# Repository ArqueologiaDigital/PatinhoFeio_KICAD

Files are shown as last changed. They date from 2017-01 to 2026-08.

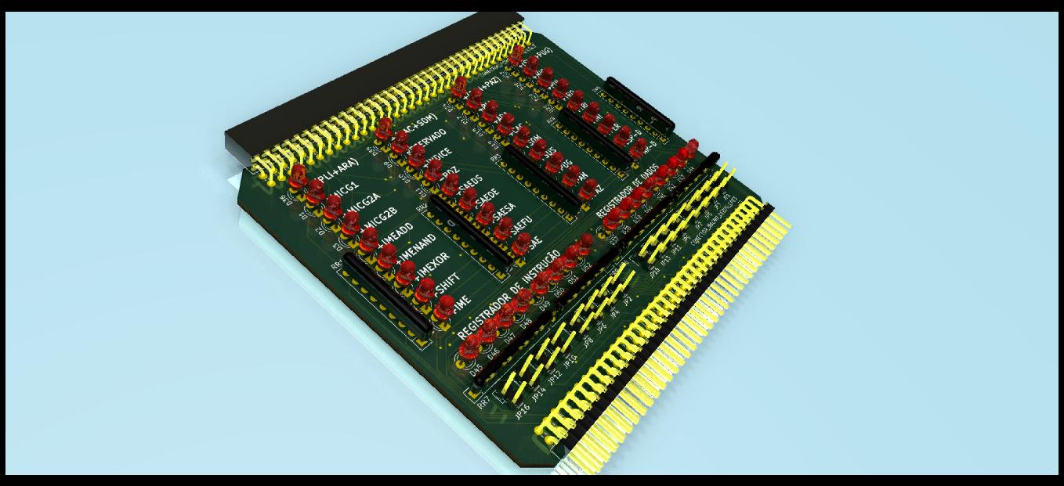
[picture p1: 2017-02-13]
CDE-3-debug/CDE-3-debug.jpg

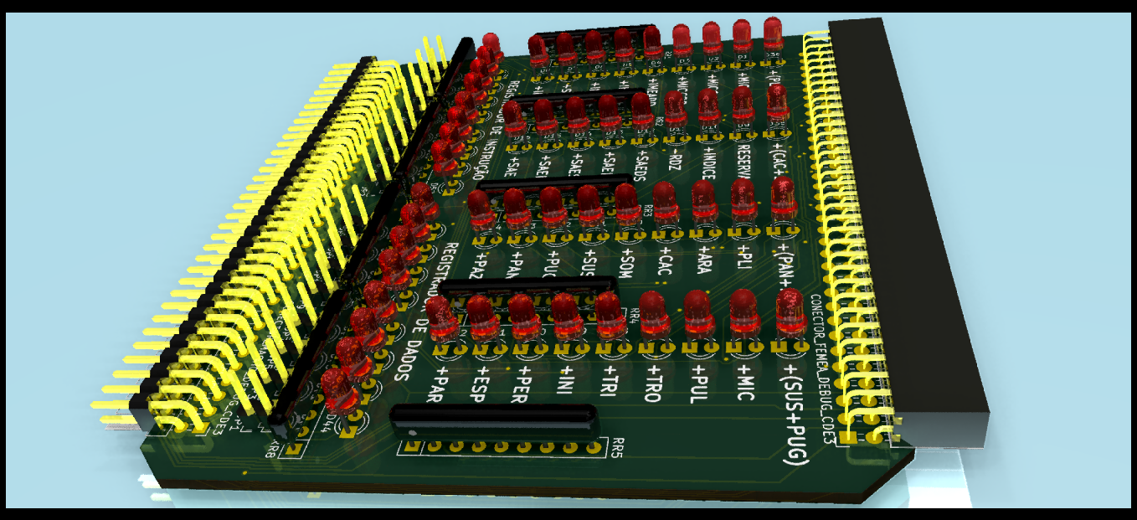
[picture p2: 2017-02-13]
CDE-3-debug/CDE-3-debug_1.png

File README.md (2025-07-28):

Para o desenvolvimento desse projeto estou atualmente (Julho de 2025) utilizando o Kicad versão 9.0.2+dfsg-1 instalado a partir do repositório de pacotes do Debian 13.
----

Existe um arquivo patinhofeio.pro na raiz desse repo que referencia os demais sub-projetos de cada placa.

Em JAN/2018 eu encomendei a fabicação das PCBs CDE-3 e CDE-3-debug. Há um relato detalhado em https://forum.fiozera.com.br/t/resgate-historico-do-computador-patinho-feio-usp-1971/58/18

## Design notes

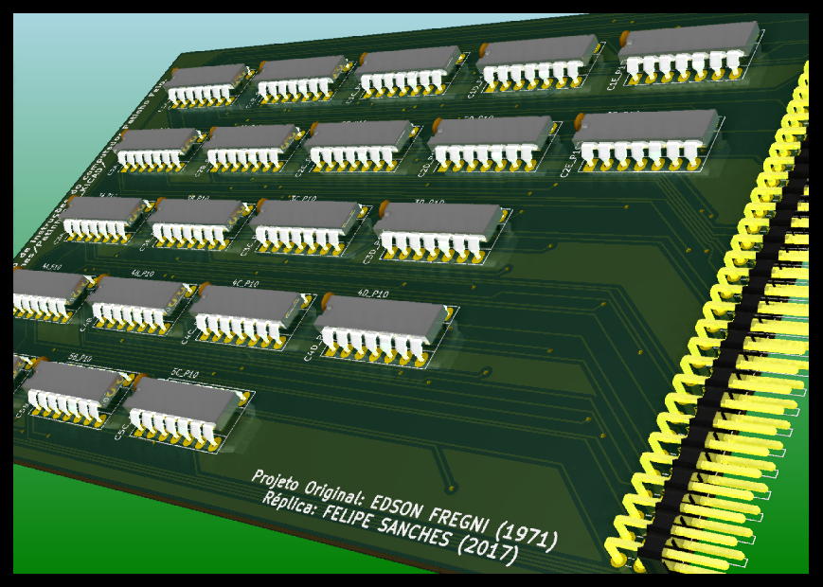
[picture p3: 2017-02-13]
CDE-3/CDE-3.png

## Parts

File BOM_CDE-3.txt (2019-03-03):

 1 7400
 7 7402
 6 7404
 5 7410
 1 7413
 1 7430
21 capacitores cerâmicos 0.1uF
21 soquete DIP14
 2 barra de pinos 90 graus 35x2 macho
 2 conector 90 graus 35x2 fêmea
 2 barra de pinos 16x2 macho
16 jumpers
60 leds vermelhos 3mm
 9 Redes resistivas 9 pinos 330ohms
 9 Redes resistivas 9 pinos 470ohms
 9 Redes resistivas 9 pinos 1k
 9 Redes resistivas 9 pinos 10k
 20 resitores 330ohms
 20 resitores 470ohms
 20 resitores 1k
 20 resitores 10k

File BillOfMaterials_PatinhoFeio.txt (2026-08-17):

== FR1-1 ==
Pastilhas:
* 1x 74LS00
* 2x SN74LS51B1
* 2x SN7454N
* 10x 74LS74

Discretos:
* 15x caps
* 1x conn_35x2

== FR2-2 ==
Pastilhas:
* 1x 74LS00
* 2x SN74LS51B1
* 2x SN7454N
* 10x 74LS74

Discretos:
* 15x caps
* 1x conn_35x2

== CRC-1 ==
Pastilhas:
* 2x 74LS00
* 8x 74LS04
* 1x 74LS10
* 4x 74LS74

Discretos:
* 15x caps
* 1x conn_35x2
* 1x XTAL (freq. ?)
* 3x BF185 (transistor TO92)
* 6 resistores sortidos (ver equemático)
* 5 caps sortidos (ver equemático)

== CDE-3 ==
Pastilhas:
* 1x 74LS00
* 7x 74LS02
* 6x 74LS04
* 5x 74LS10
* 1x 74LS20
* 1x 74LS30

Discretos:
* 21x caps
* 1x conn_35x2

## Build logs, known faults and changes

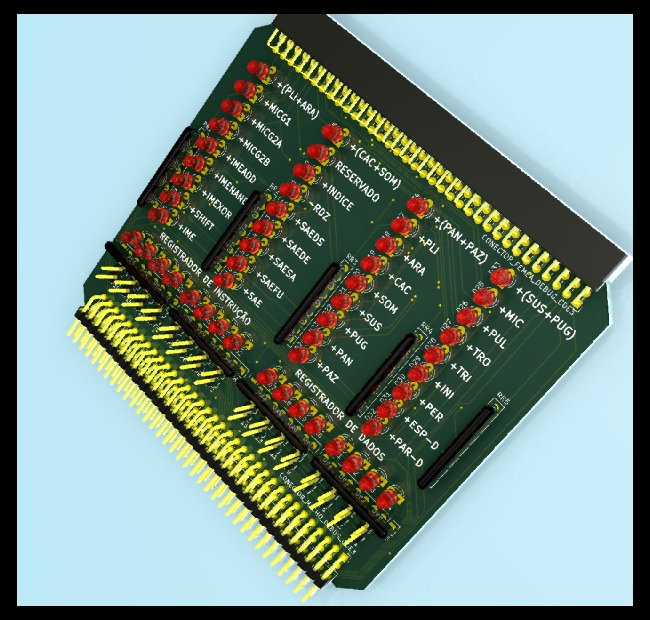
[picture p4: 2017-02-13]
CDE-3-debug/CDE-3-debug_2.png

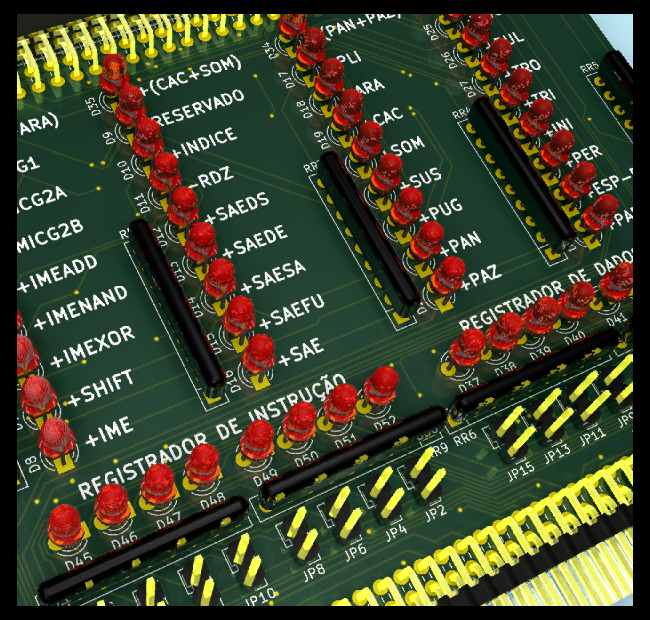
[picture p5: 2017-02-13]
CDE-3-debug/CDE-3-debug_3.png

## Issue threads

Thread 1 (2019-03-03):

CDE-3 (rev b)

felipesanches, 2019-03-03:
A primeira placa CDE-3 produzida tinha alguns erros que foram corrigidos manualmente. Seria bom atualizar o desenho da PCB para que seja possível fabricar uma segunda revisão sem esses erros.

- [ ] Atualizar roteamento da PCB
- [ ] Garantir que passa nos testes de DRC
- [ ] Gerar os gerbers
- [ ] Aplicar tag CDE3_rev_B no repositório
- [ ] Encomendar fabricação da PCB

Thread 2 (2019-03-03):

Prancha XI: Identificar componente 4E

felipesanches, 2019-03-03:
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

É um chip de lógica booleana composto que interliga 4 portas AND a uma porta NOR.

felipesanches, 2019-03-03:
Trata-se de um chip conhecido como "AND-OR-INVERT". É parecido com esse: http://www.applelogic.org/files/74LS54.pdf Mas tem uma outra distribuição de quantidades de inputs.

Estamos procurando algo como `2-4-4-2-INPUT AND-OR-INVERT GATE`.

felipesanches, 2019-03-03:
Essa mesma prancha tem um outro CI que parece ser do mesmo tipo:

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

felipesanches, 2019-03-03:
É muito difícil de ler o que está escrito. Mas parece ser:

Primeira porta AND:
* 2A1
* 2A13

Segunda porta AND:
* 1A13
* 1A2
* 1A1
* 1A3

Terceira porta AND:
* 1A6 (ou 1A8?)
* 1A4
* 1A5
* 1A?

Quarta porta AND:
* 2A8
* 2A10

E a saída da porta NOR parece ser no pino 8. Mas pode também ser pino 6 talvez...

Como constam pinos do chip 1A e 2A, uma hipótese é de que esse símbolo esteja representando duas pastilhas simultaneamente. De fato não consegui achar nenhuma pastilha composta AND-OR-INVERT com esse layout de 2-4-4-2 inputs. Vou tentar encontrar alguma combinação de outras pastilhas AND-OR-INVERT que quando combinadas sejam compatíveis com a pinagem desse diagrama.

lucasalberto01, 2023-08-31:
Consegui encontrar a pastilha _SN74S64_ que é muito próxima, talvez tenham mudado a ordem dos blocos, a pinagem em boa parte é parecida.

Segue o link do PDF do datasheet https://www.ti.com/lit/ds/symlink/sn54s64.pdf

lucasalberto01, 2023-08-31:
Acho que descobri uma coisa... Contando os pinos, vi que na verdade estão usando **13 pinos**, e os 74 tem 14 pinos, 12 são lógicos, 1 para positivo (5v), e 1 para negativo...

 E ali tem dois pinos que estão indo para o terra.... Quem desenhou o esquema provavelmente contou a ligação para o terra como um pino de entra da porta, quando na verdade é só a ligação do negativo do CI com o negativo da alimentação do PC!

lucasalberto01, 2023-08-31:
Uma coisa estranha que percebi é que ali tem 13 pinos usados, e a família 7400 usa 14 pinos

lucasalberto01, 2023-09-11:
Outro circuito integrado, pode ser o 74LS54 **antigo**, o antigo é diferente do novo, era usado no computador HP 9825

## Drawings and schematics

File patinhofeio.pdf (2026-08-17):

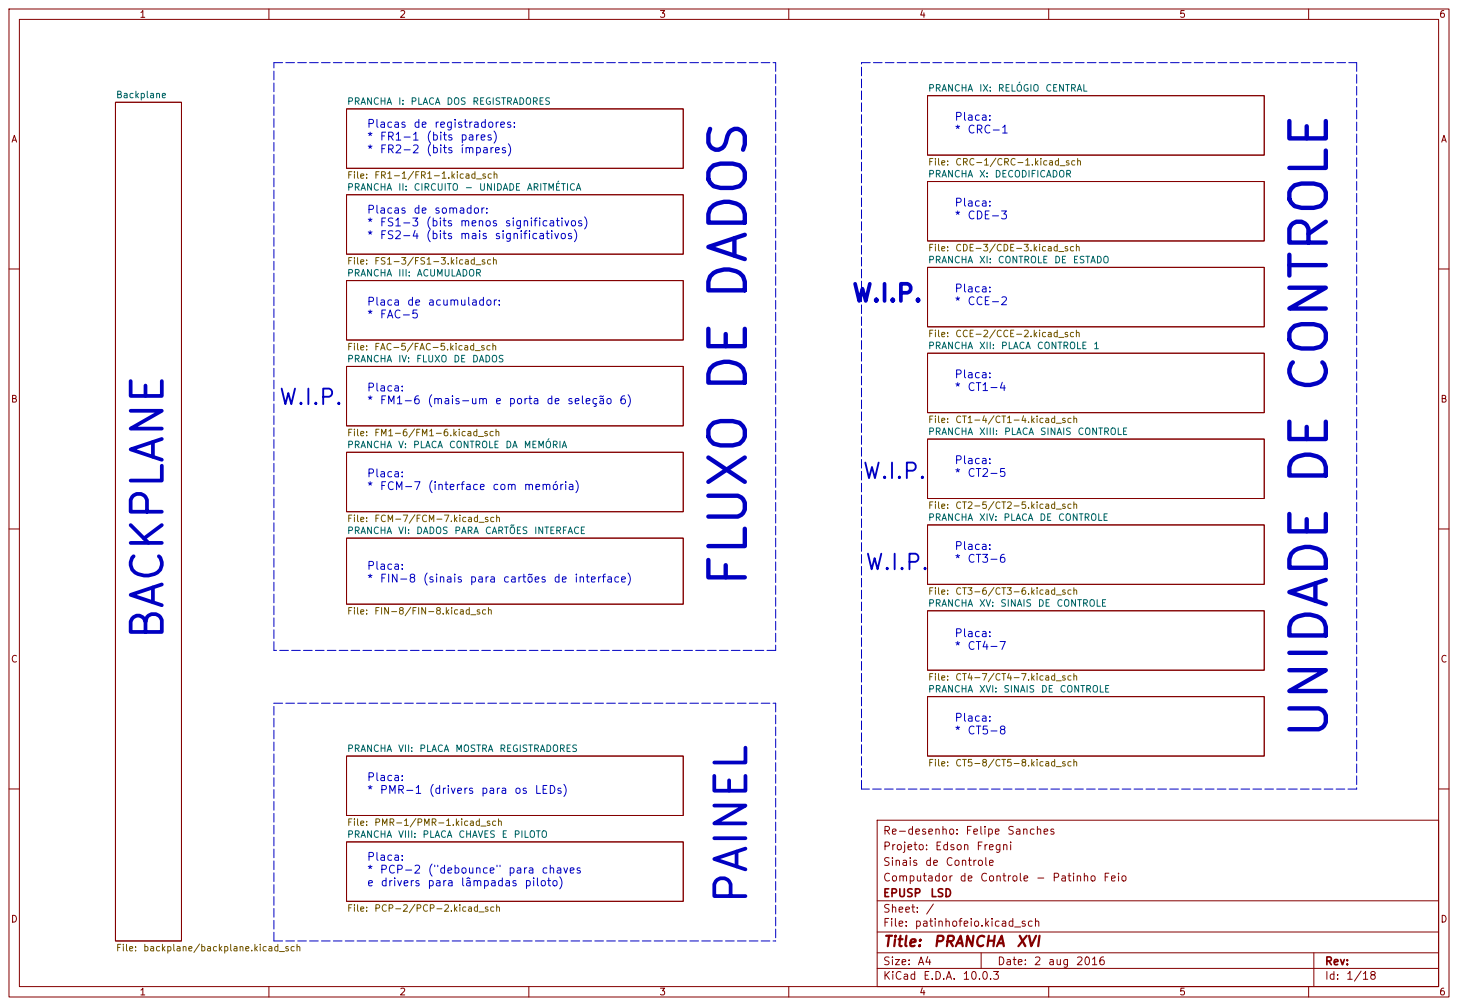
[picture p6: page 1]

File: FCM-7/FCM-7.kicad_sch PRANCHA I: PLACA DOS REGISTRADORES
Placas de registradores:
* FR1-1 (bits pares)
File: FS1-3/FS1-3.kicad_sch PRANCHA VII: PLACA MOSTRA REGISTRADORES
File: CT2-5/CT2-5.kicad_sch PRANCHA III: ACUMULADOR
* CCE-2 PAINEL

File: CCE-2/CCE-2.kicad_sch PRANCHA IX: RELÓGIO CENTRAL File: CRC-1/CRC-1.kicad_sch PRANCHA X: DECODIFICADOR

File: FR1-1/FR1-1.kicad_sch PRANCHA II: CIRCUITO - UNIDADE ARITMÉTICA

File: CDE-3/CDE-3.kicad_sch PRANCHA XII: PLACA CONTROLE 1

File: FAC-5/FAC-5.kicad_sch PRANCHA IV: FLUXO DE DADOS

Placa:
* FM1-6 (mais-um e porta de seleção 6)

File: CT1-4/CT1-4.kicad_sch PRANCHA XVI: SINAIS DE CONTROLE
File: CT4-7/CT4-7.kicad_sch PRANCHA XIII: PLACA SINAIS CONTROLE

File: FM1-6/FM1-6.kicad_sch PRANCHA V: PLACA CONTROLE DA MEMÓRIA

* FCM-7 (interface com memória)

File: CT5-8/CT5-8.kicad_sch PRANCHA XIV: PLACA DE CONTROLE

Re-desenho: Felipe Sanches PRANCHA VI: DADOS PARA CARTÕES INTERFACE

* FIN-8 (sinais para cartões de interface)

File: CT3-6/CT3-6.kicad_sch PRANCHA XV: SINAIS DE CONTROLE

* PMR-1 (drivers para os LEDs)

File: PMR-1/PMR-1.kicad_sch PRANCHA VIII: PLACA CHAVES E PILOTO

Projeto: Edson Fregni
Sinais de Controle
Computador de Controle - Patinho Feio
EPUSP LSD
Sheet: /
File: patinhofeio.kicad_sch
Title: PRANCHA XVI

* PCP-2 ("debounce" para chaves e drivers para lâmpadas piloto)

Size: A4 | Rev:
KiCad E.D.A. 10.0.3 | Id: 1/18

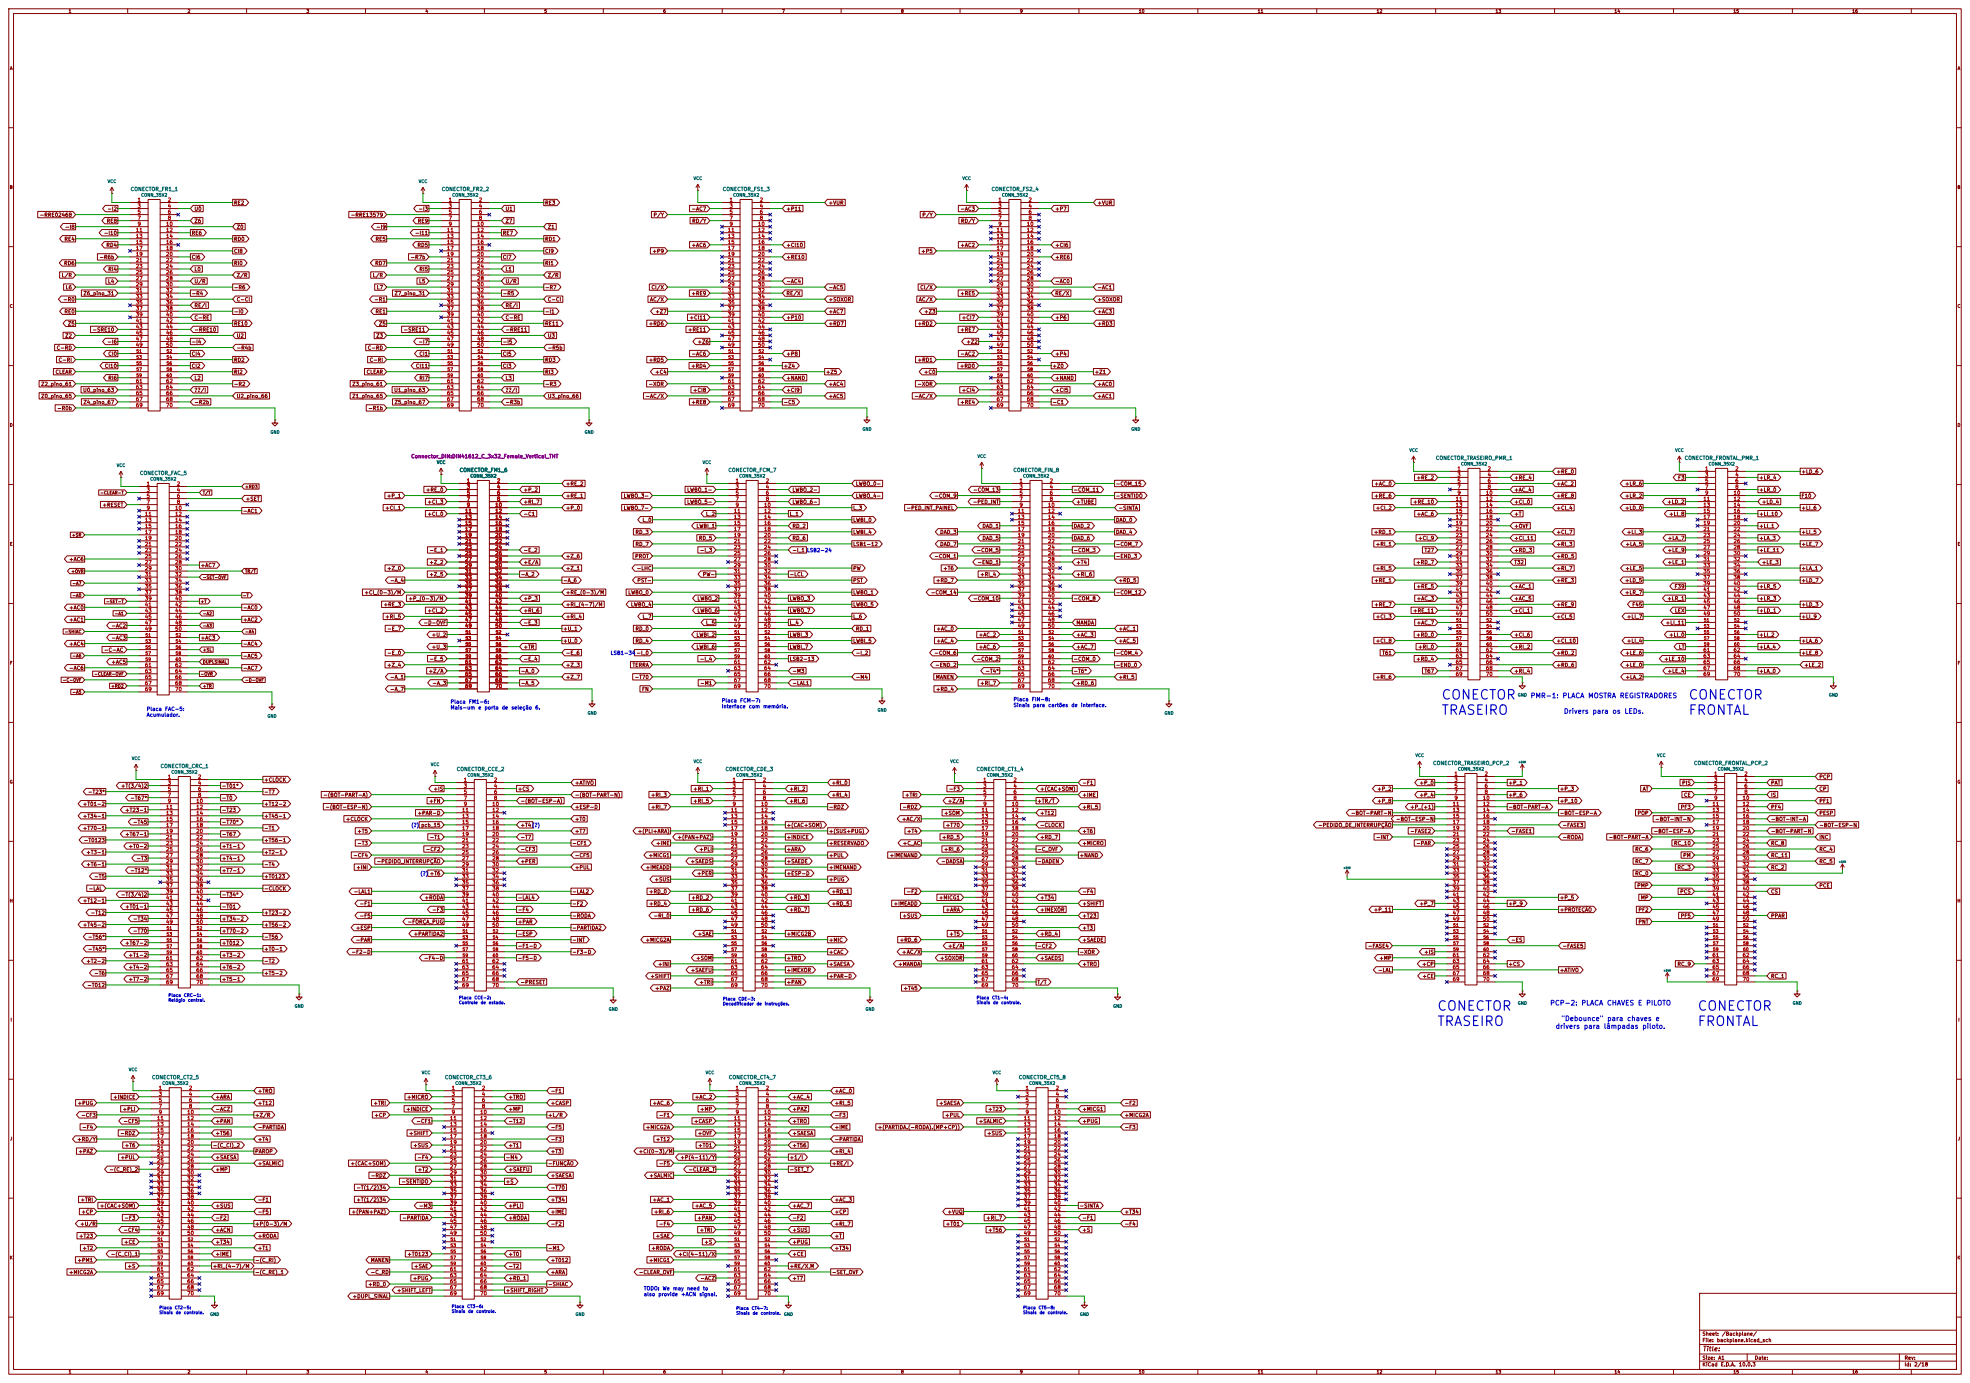
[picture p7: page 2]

PMR-1: PLACA MOSTRA REGISTRADORES
GND

Placa FM1-6:
Mais-um e porta de seleção 6.

Placa FIN-8:
Sinais para cartões de interface.

Drivers para os LEDs.

PCP-2: PLACA CHAVES E PILOTO

"Debounce" para chaves e
drivers para lâmpadas piloto.

+(PARTIDA.(-RODA).(MP+CP))

TODO: We may need to
also provide +ACN signal.

Placa CT3-6: Sinais de controle.

Placa CT5-8: Sinais de controle. Placa CT2-5: Sinais de controle.

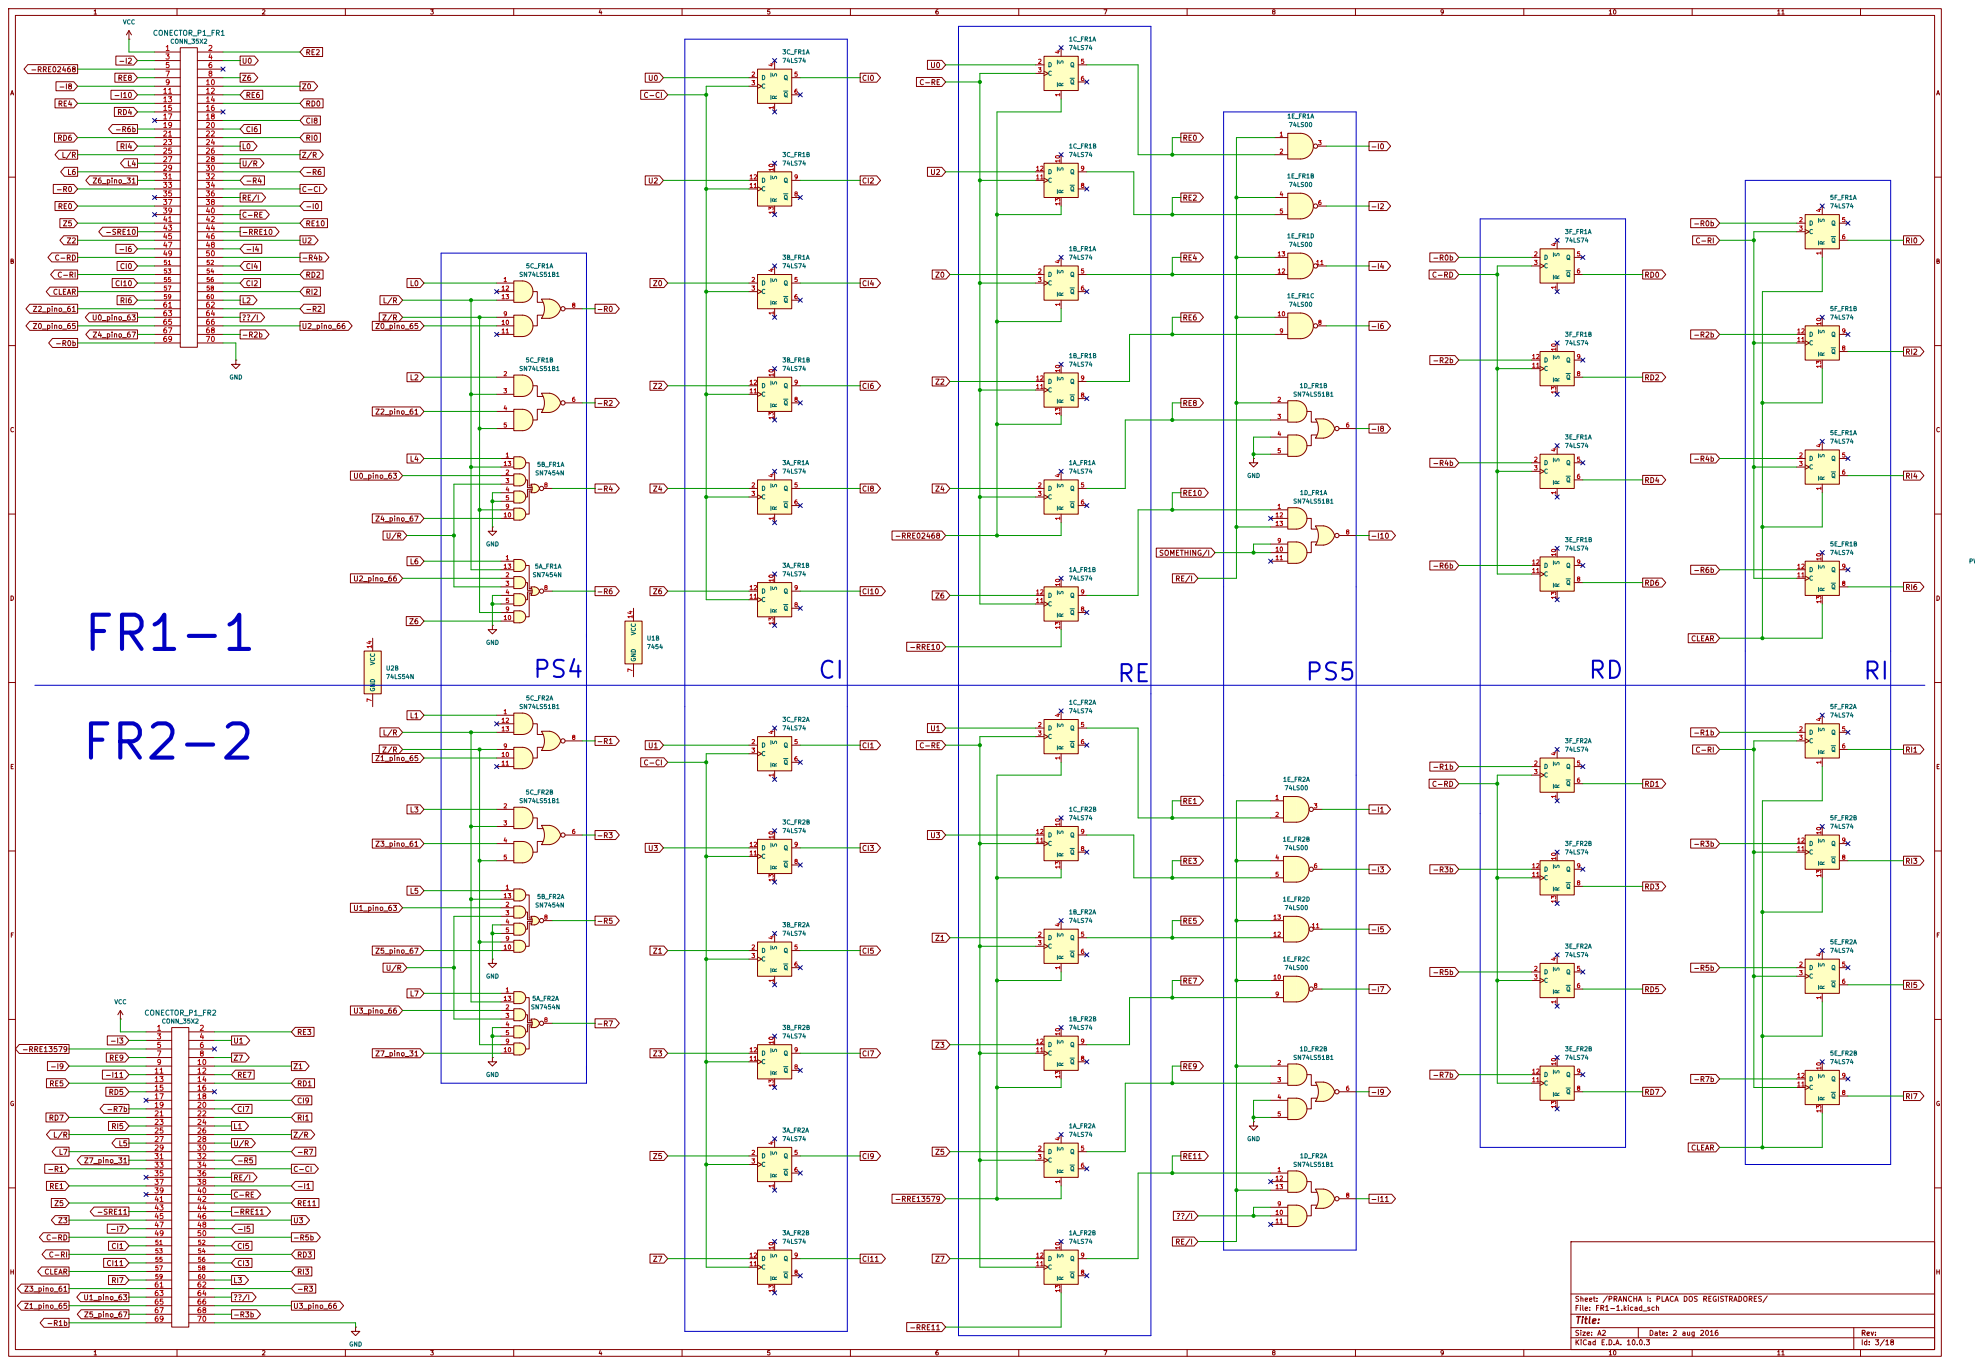
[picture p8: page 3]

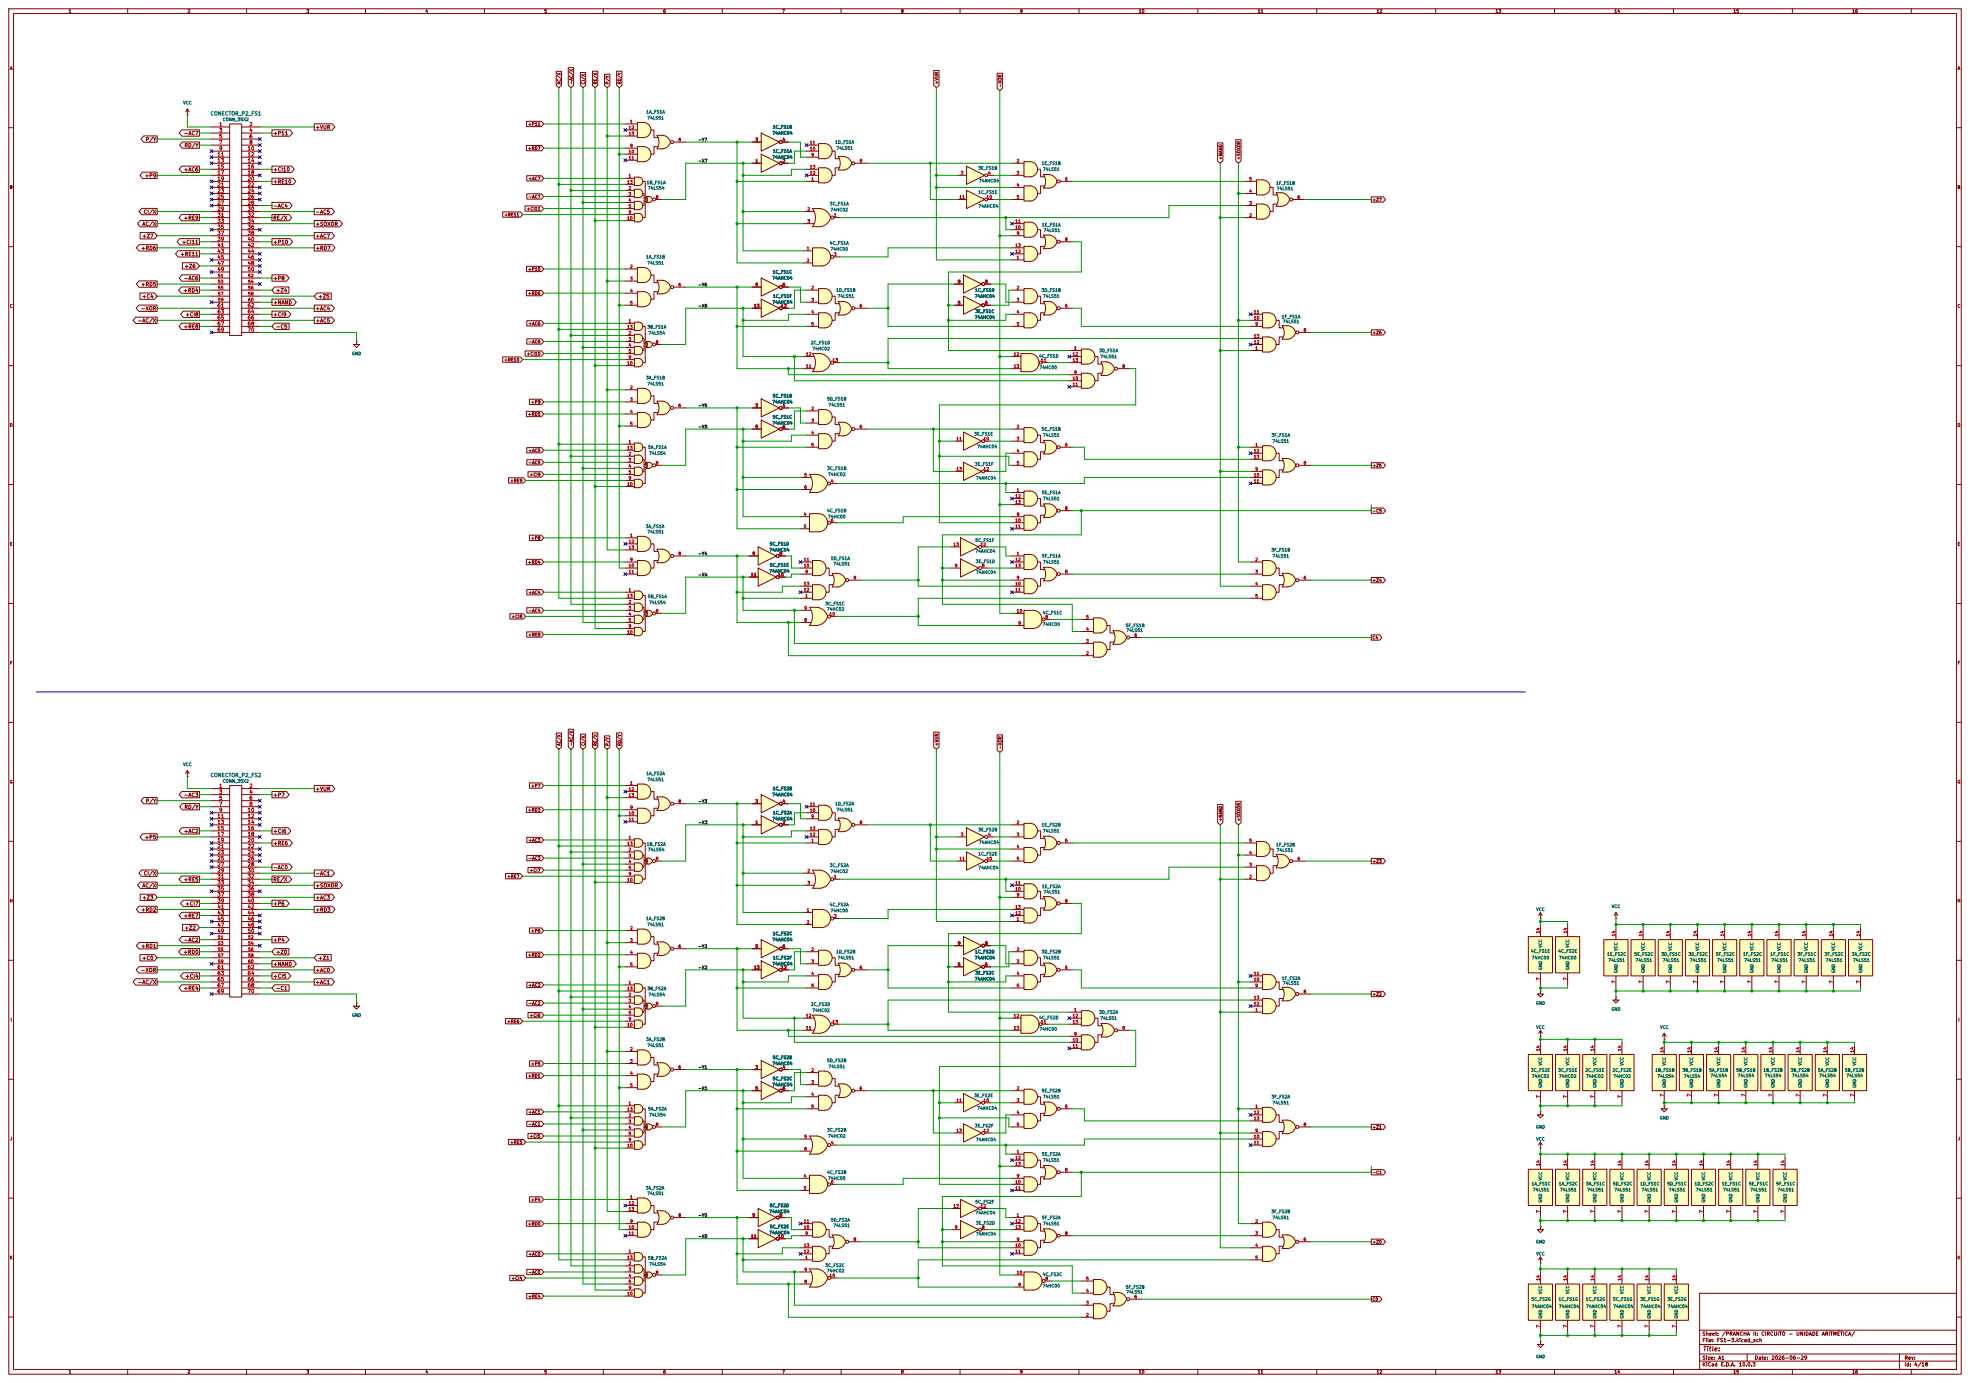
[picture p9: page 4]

3E_FS2E 74AHC04 11 10

3E_FS2F 74AHC04 13 12

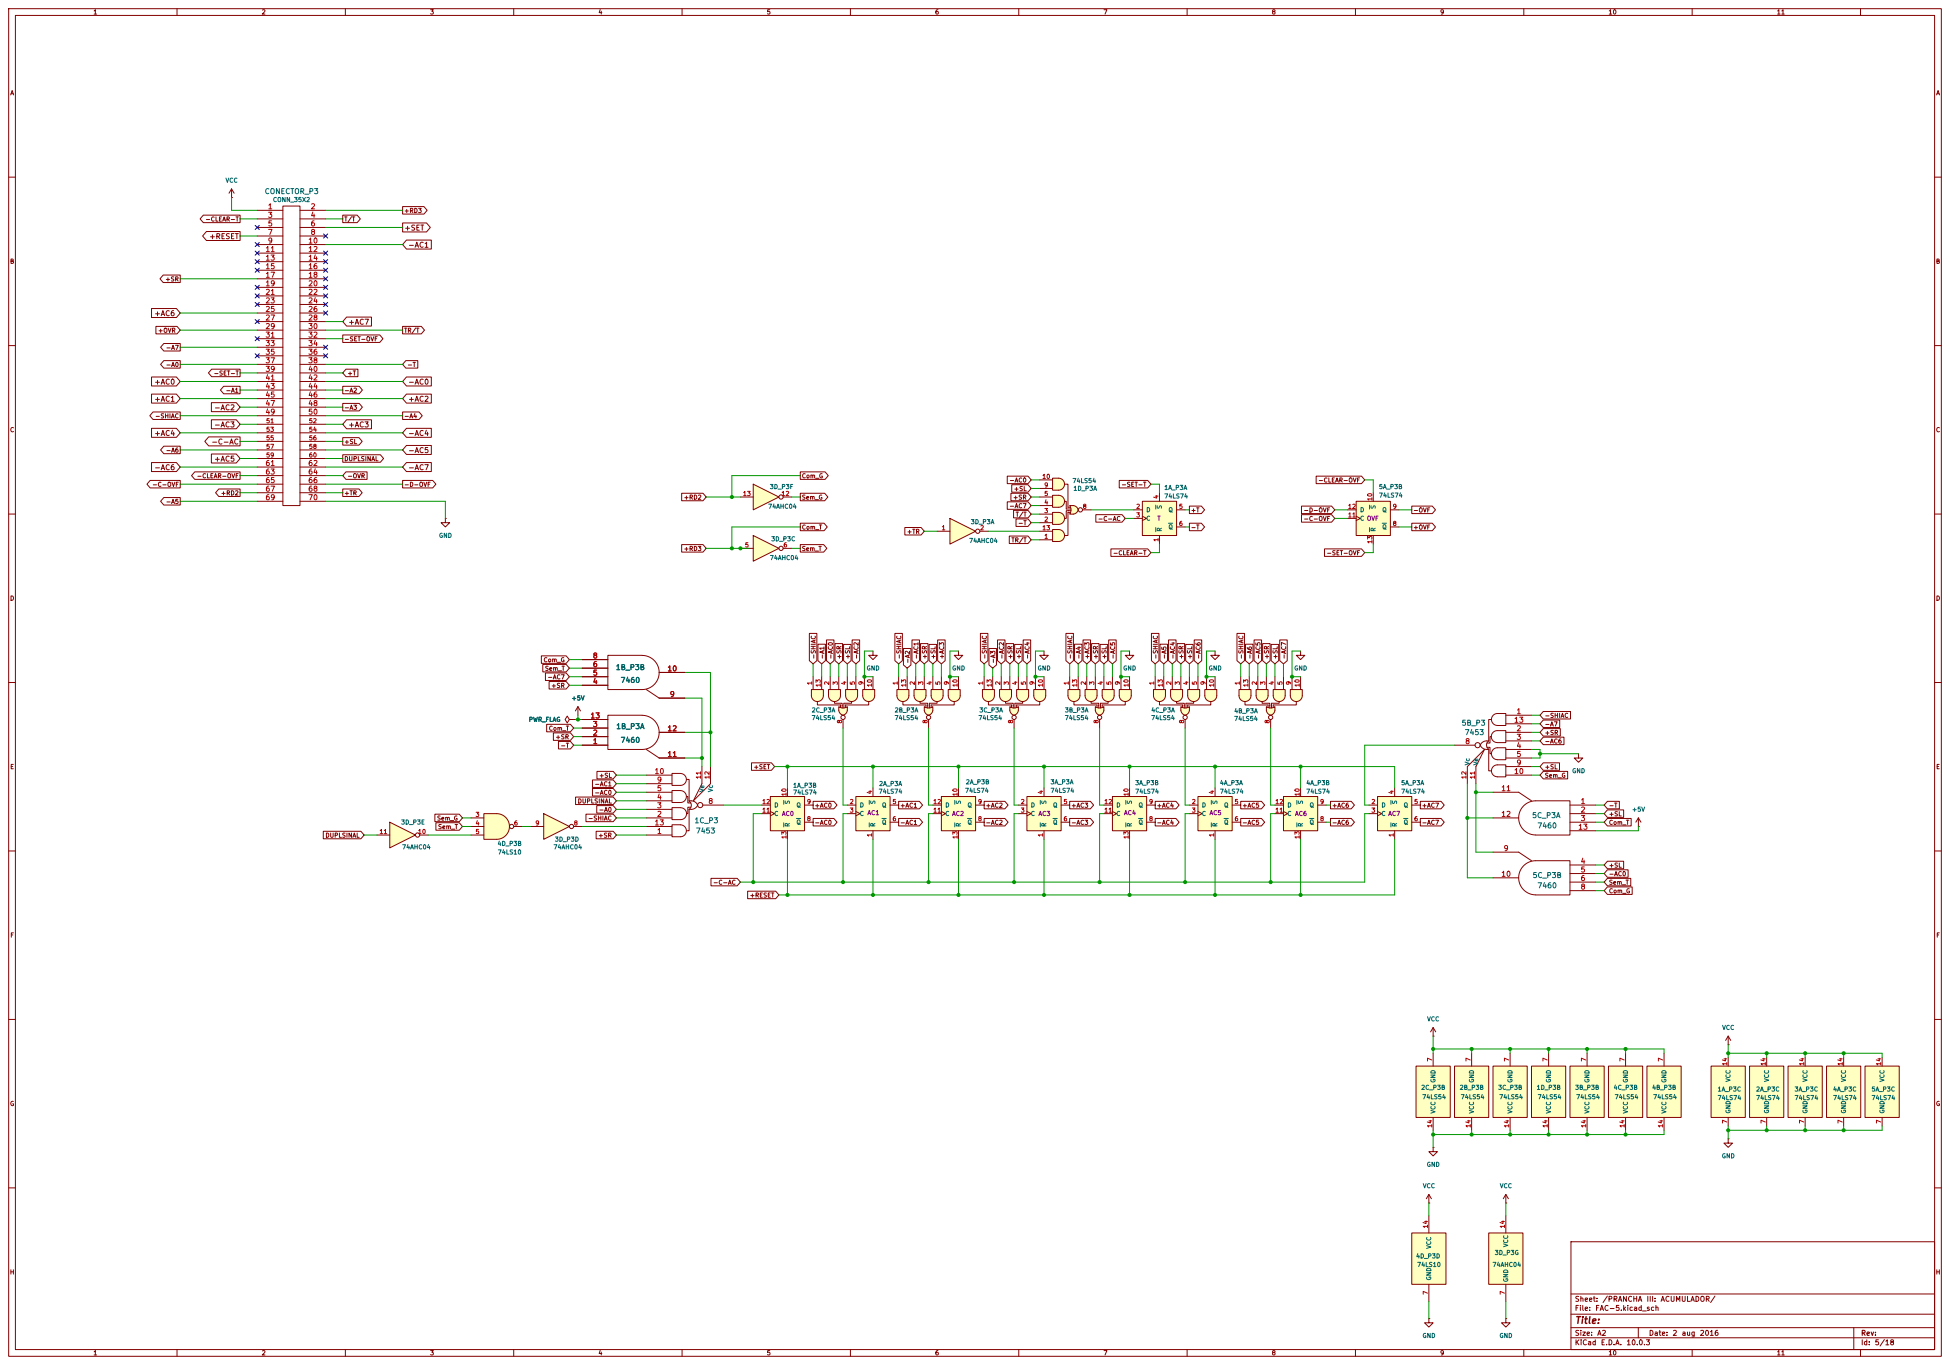
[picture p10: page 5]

Sheet: /PRANCHA III: ACUMULADOR/
File: FAC-5.kicad_sch

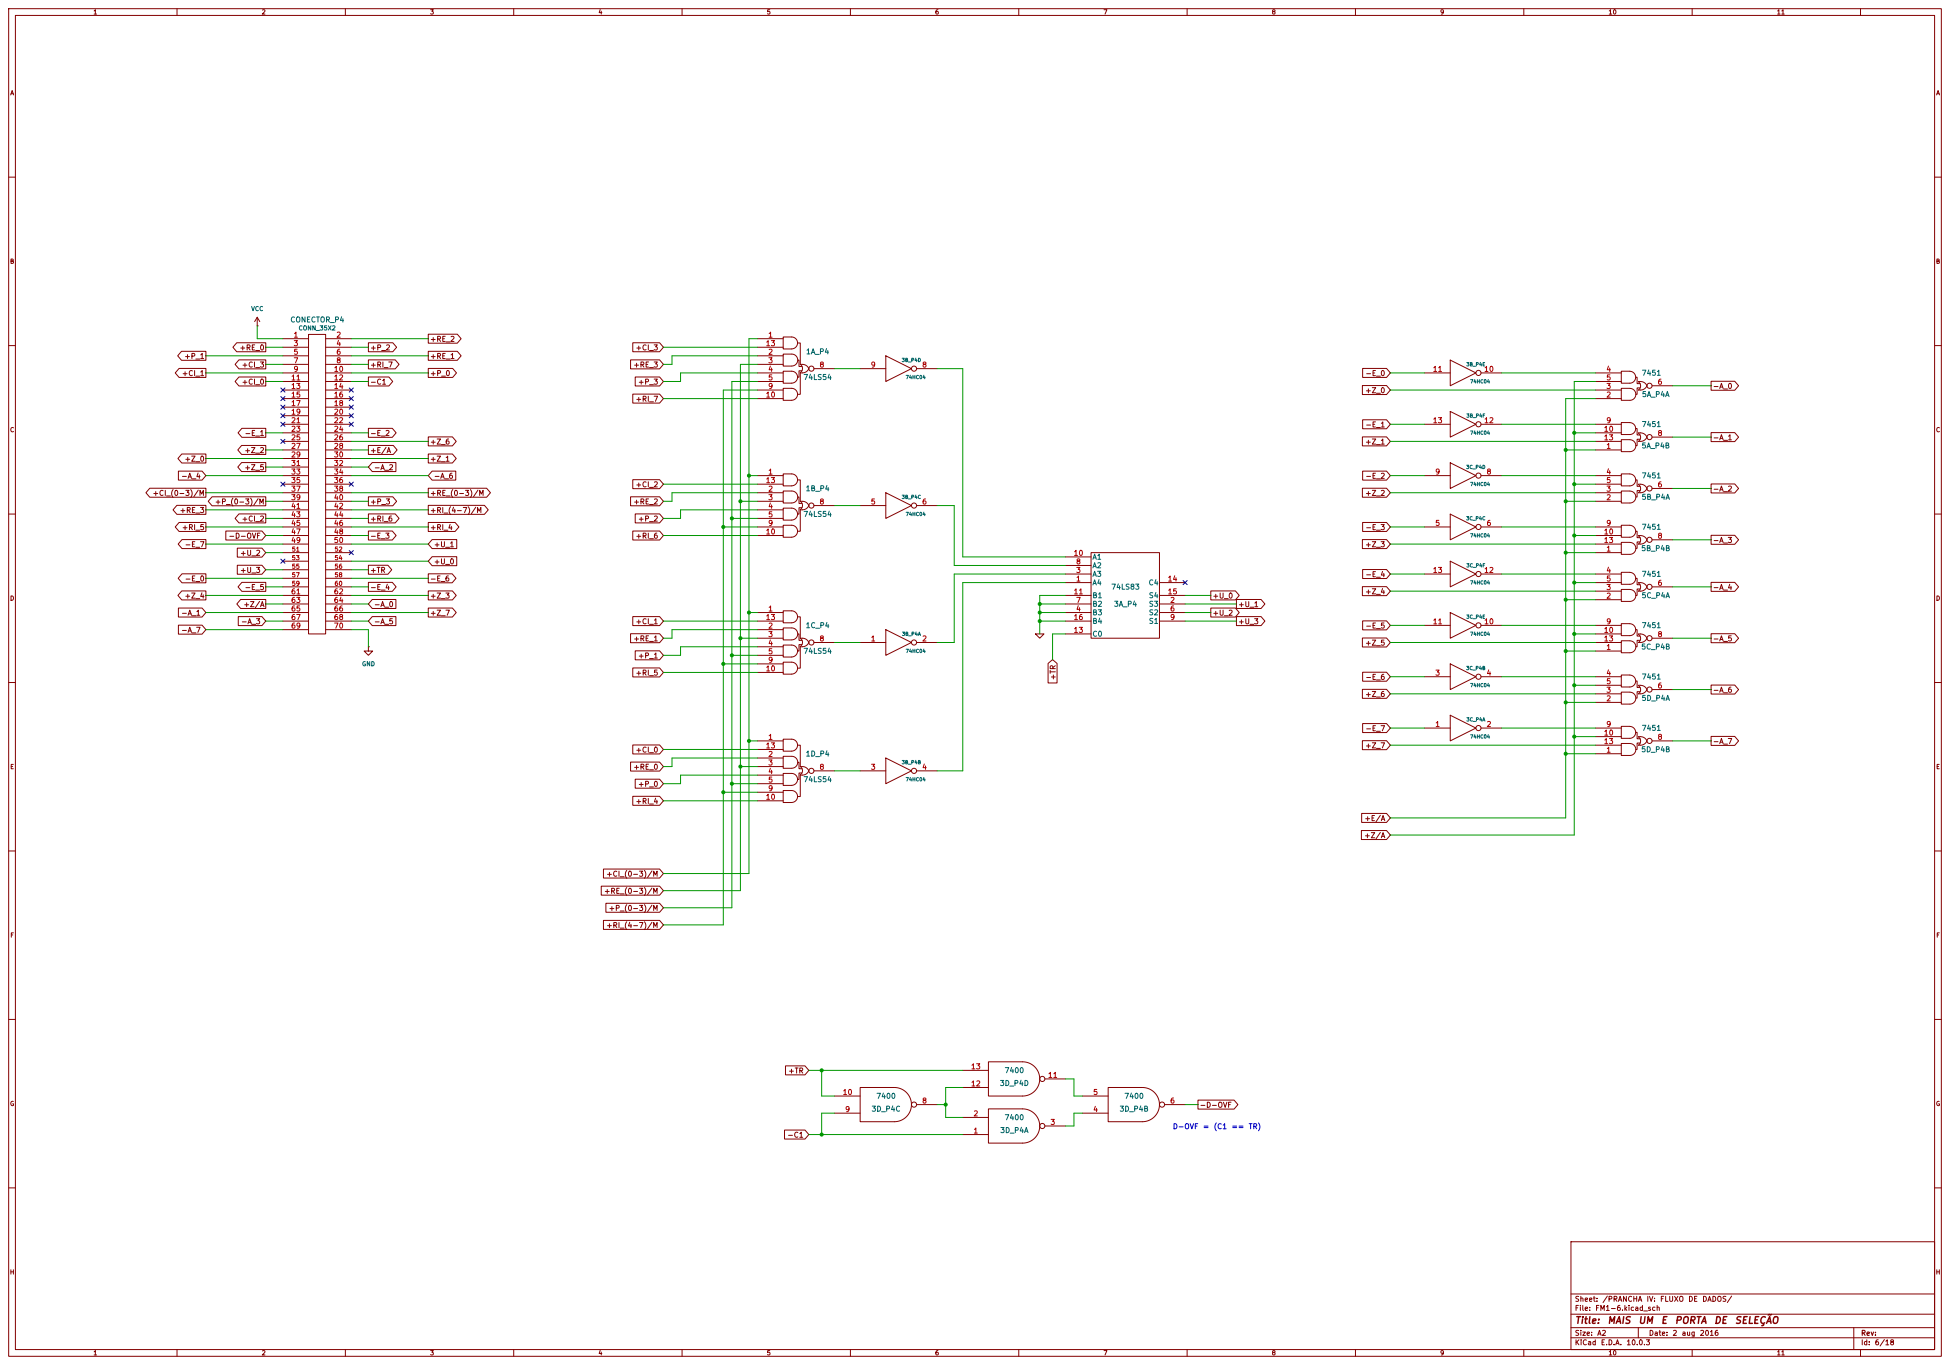
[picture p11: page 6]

Sheet: /PRANCHA IV: FLUXO DE DADOS/
File: FM1-6.kicad_sch
Title: MAIS UM E PORTA DE SELEÇÃO

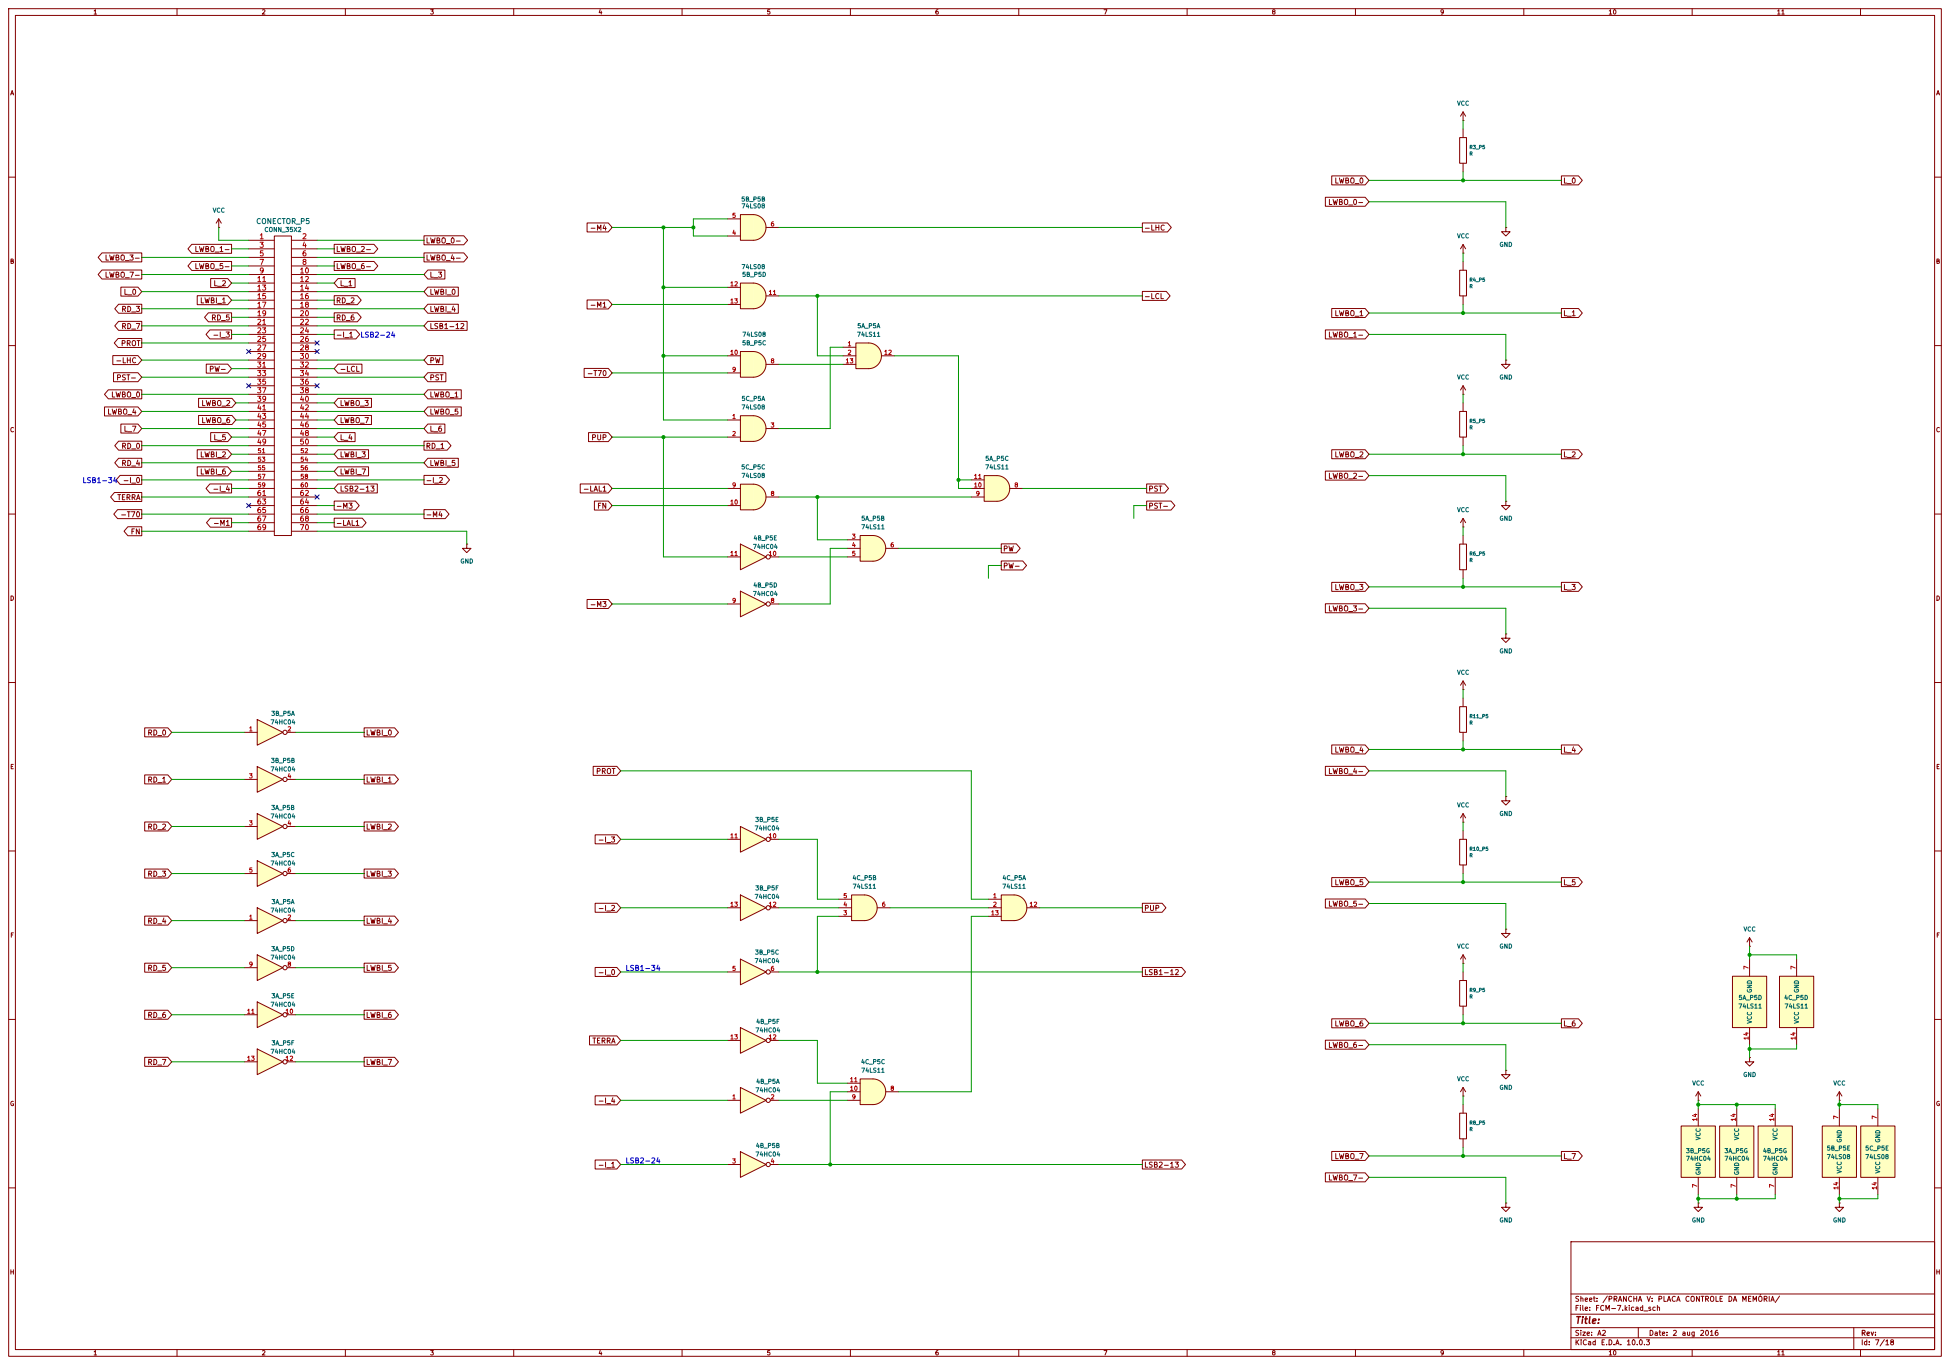
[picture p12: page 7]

Sheet: /PRANCHA V: PLACA CONTROLE DA MEMÓRIA/
File: FCM-7.kicad_sch

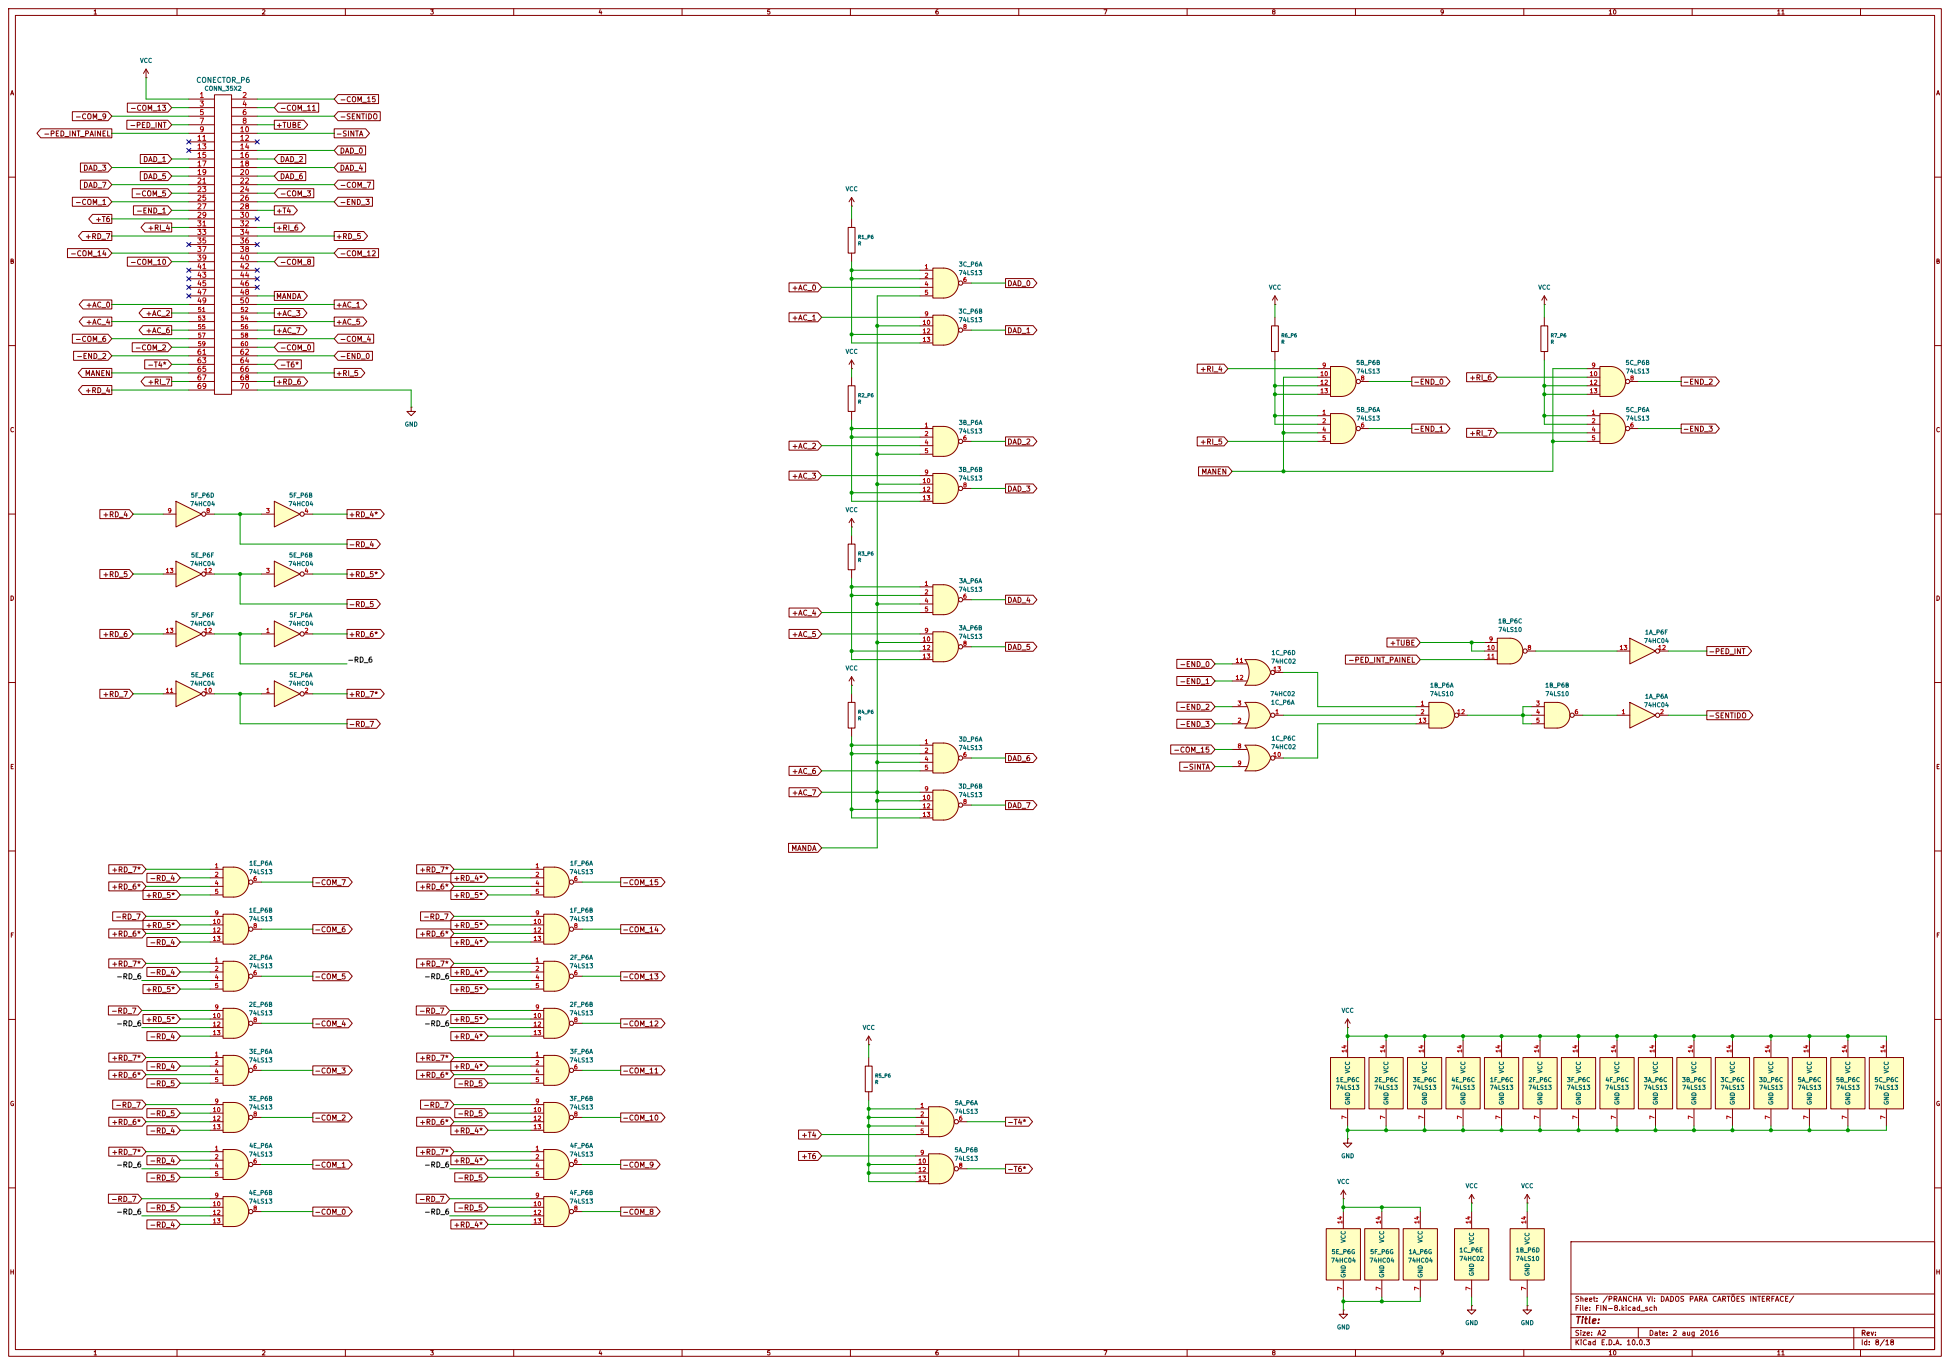
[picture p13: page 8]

Sheet: /PRANCHA VI: DADOS PARA CARTÕES INTERFACE/ GND 7 VCC 14

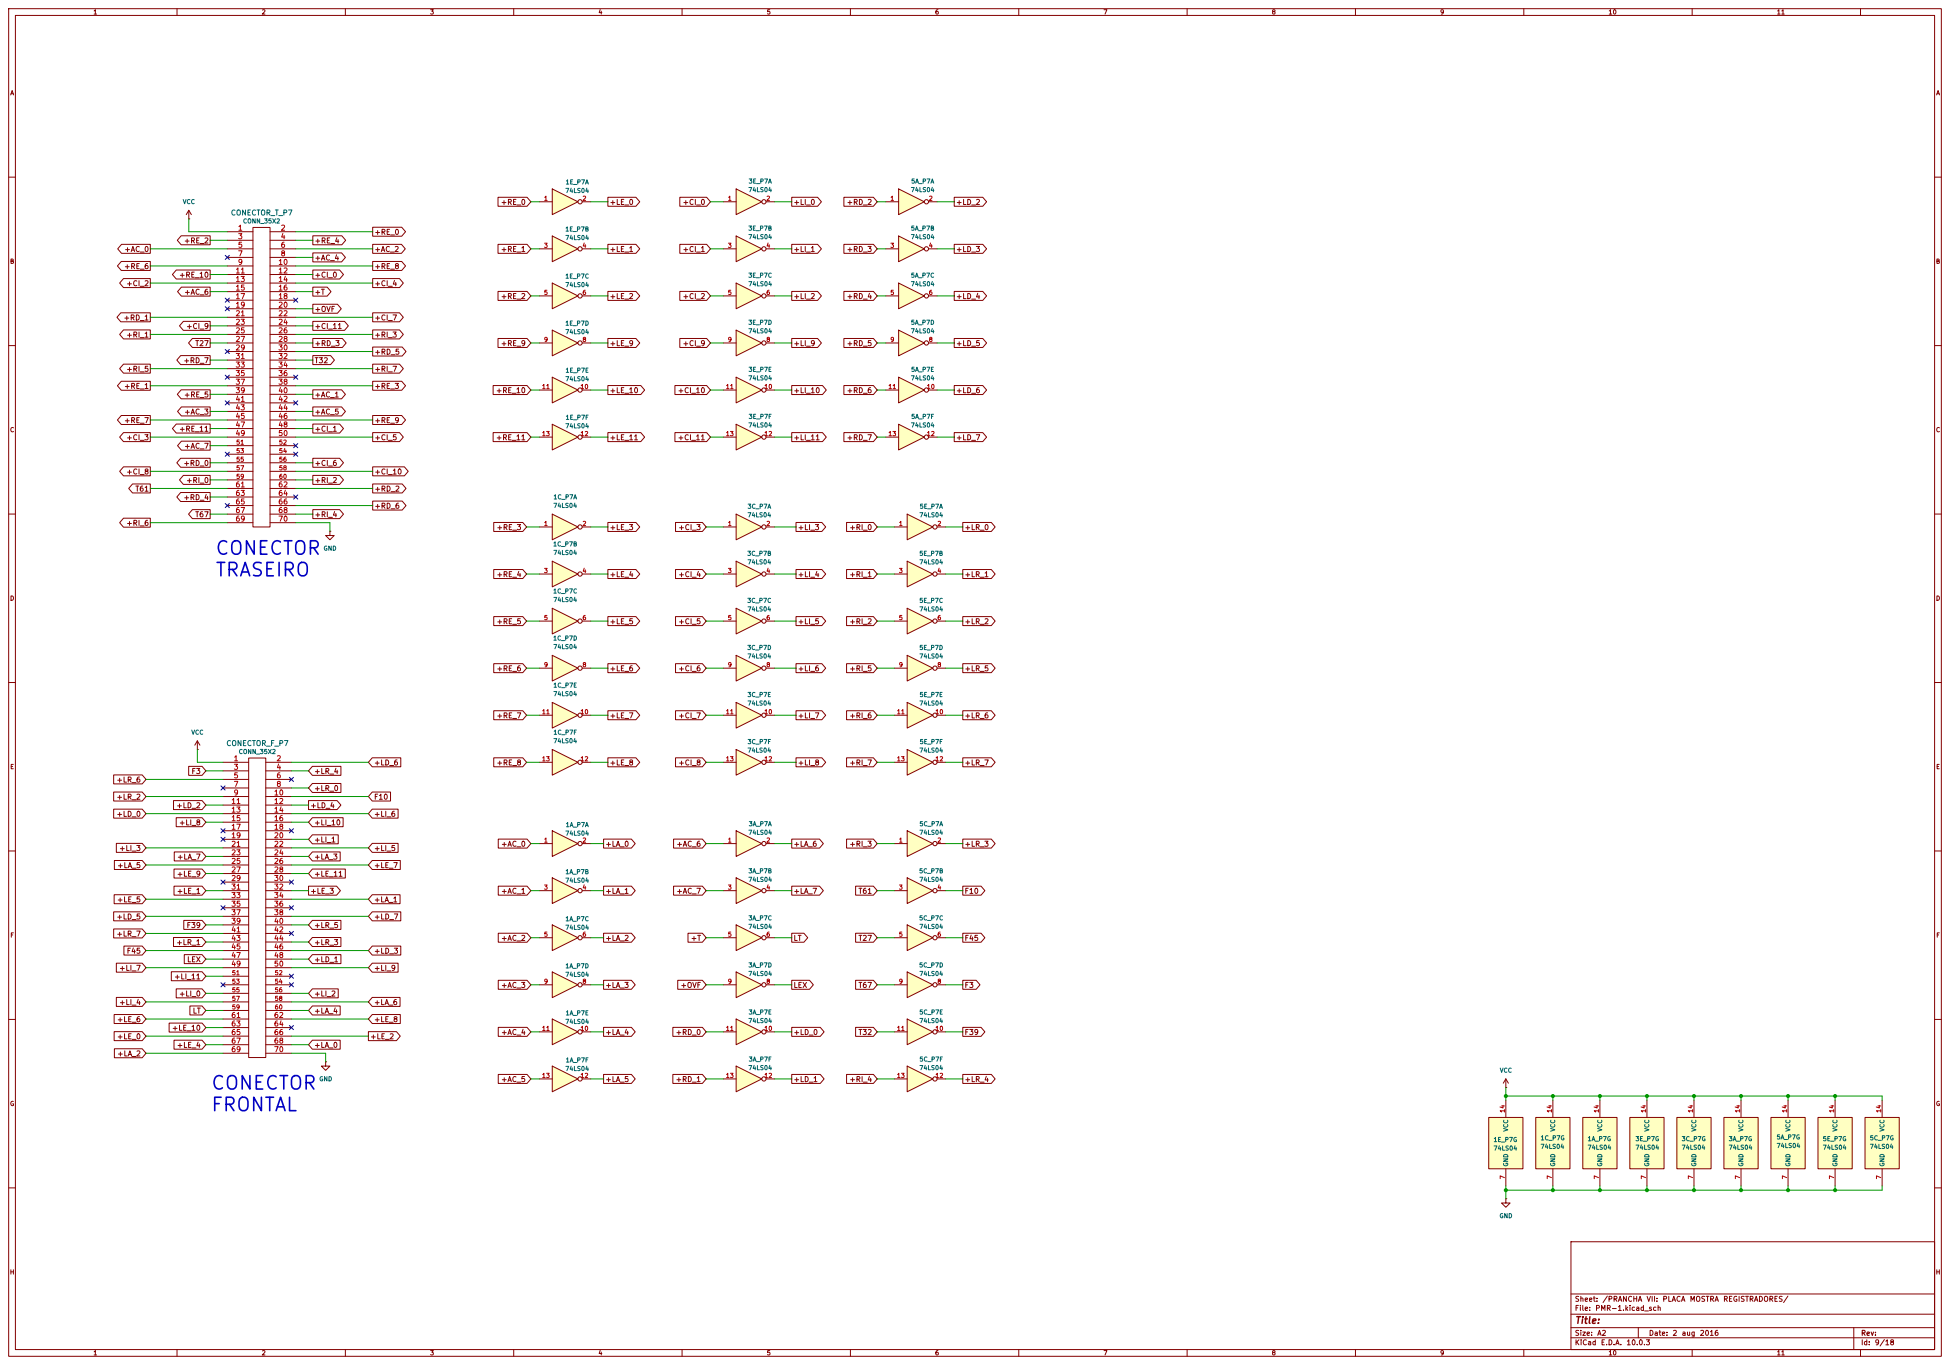
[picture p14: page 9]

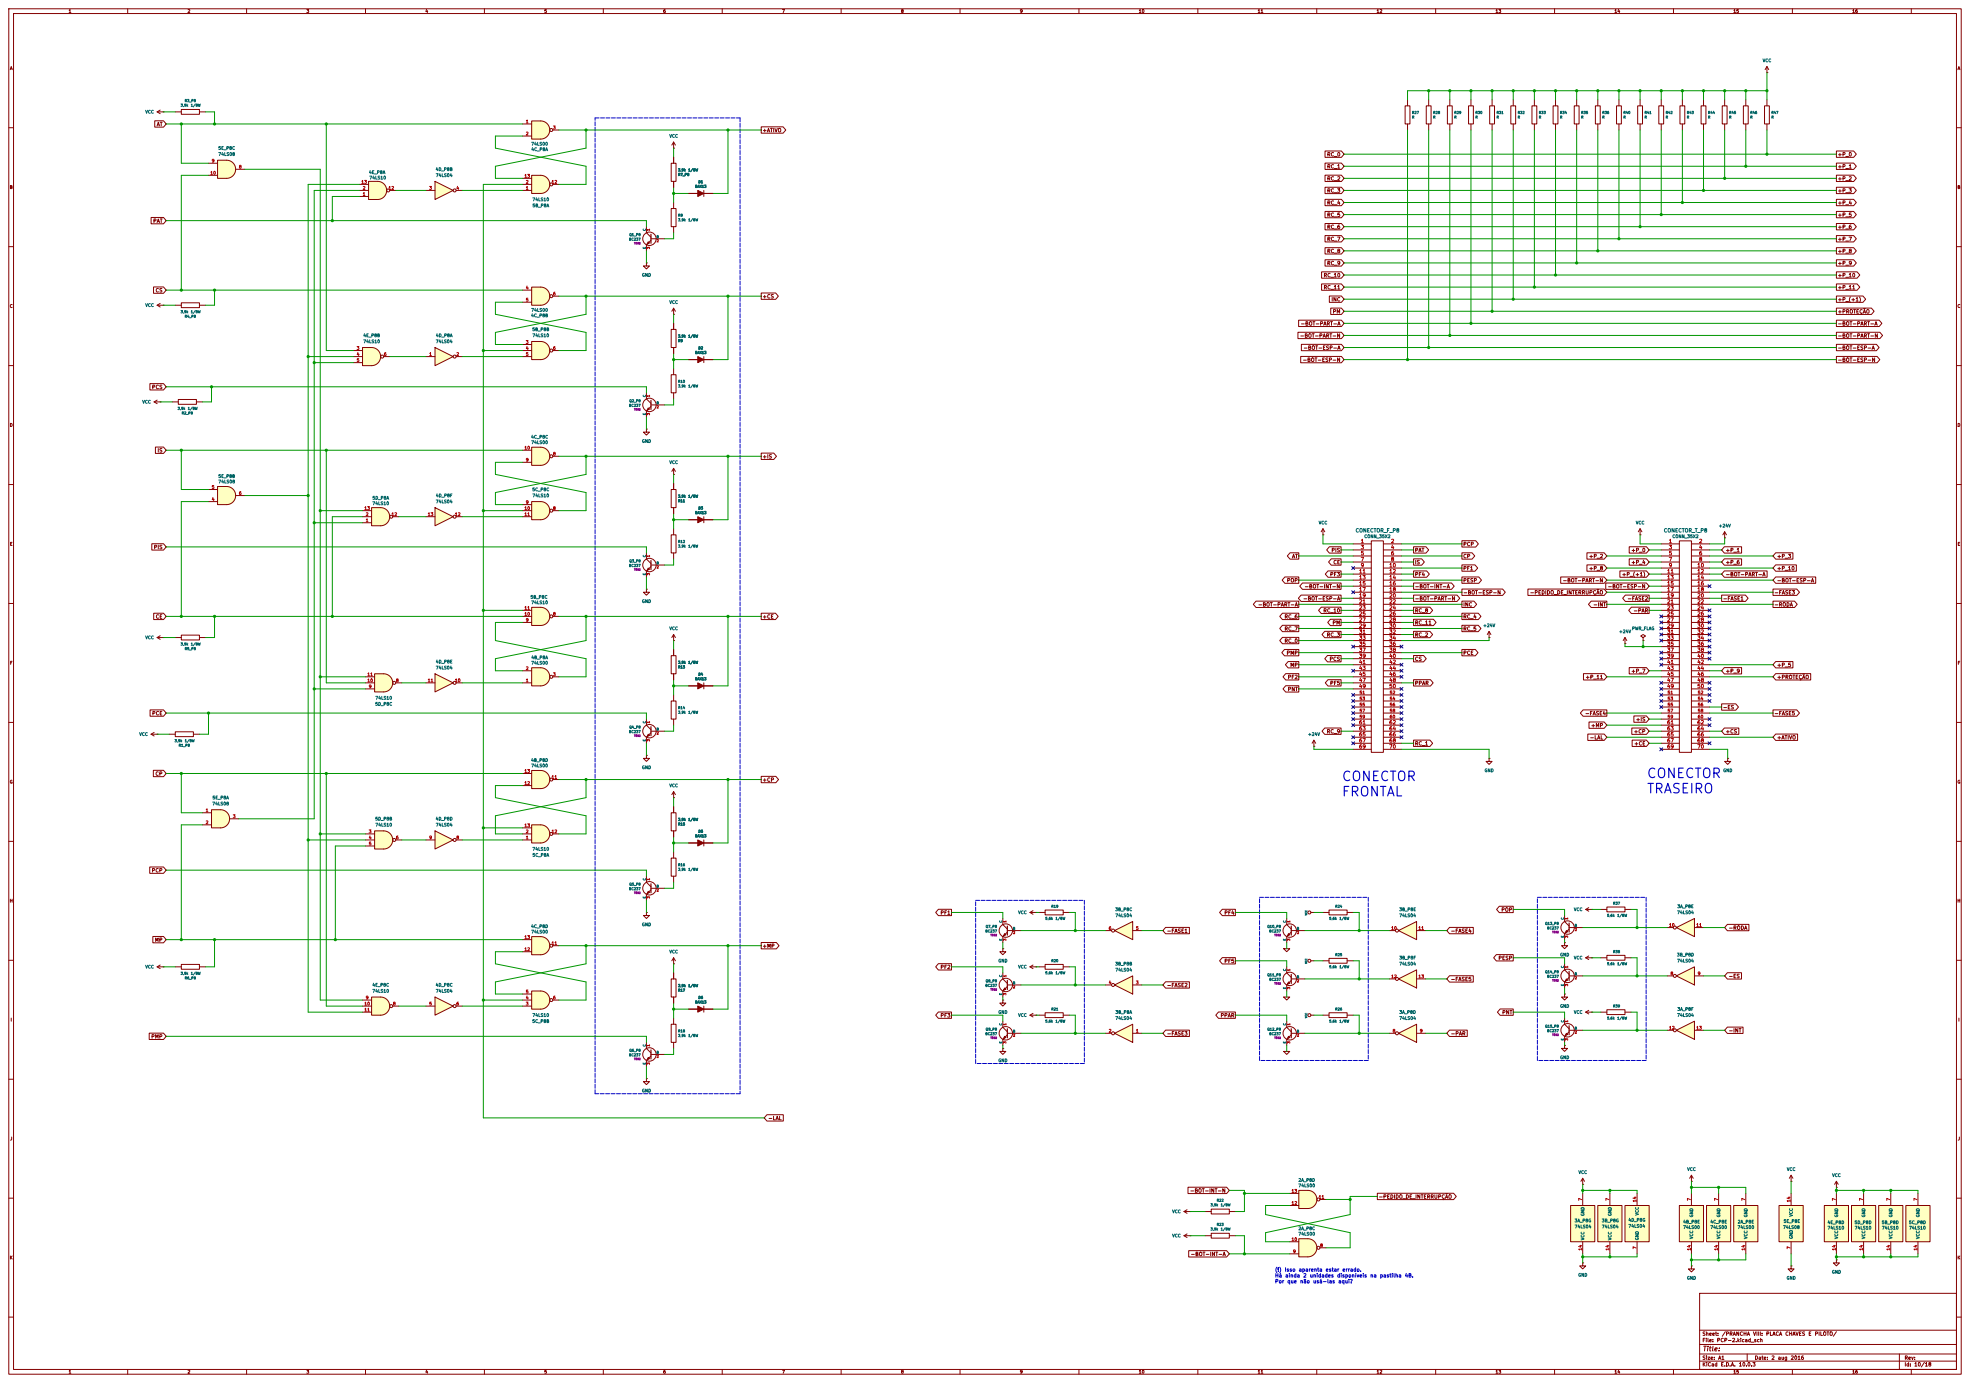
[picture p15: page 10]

(!) Isso aparenta estar errado.
Há ainda 2 unidades disponíveis na pastilha 4B.
Por que não usá-las aqui?

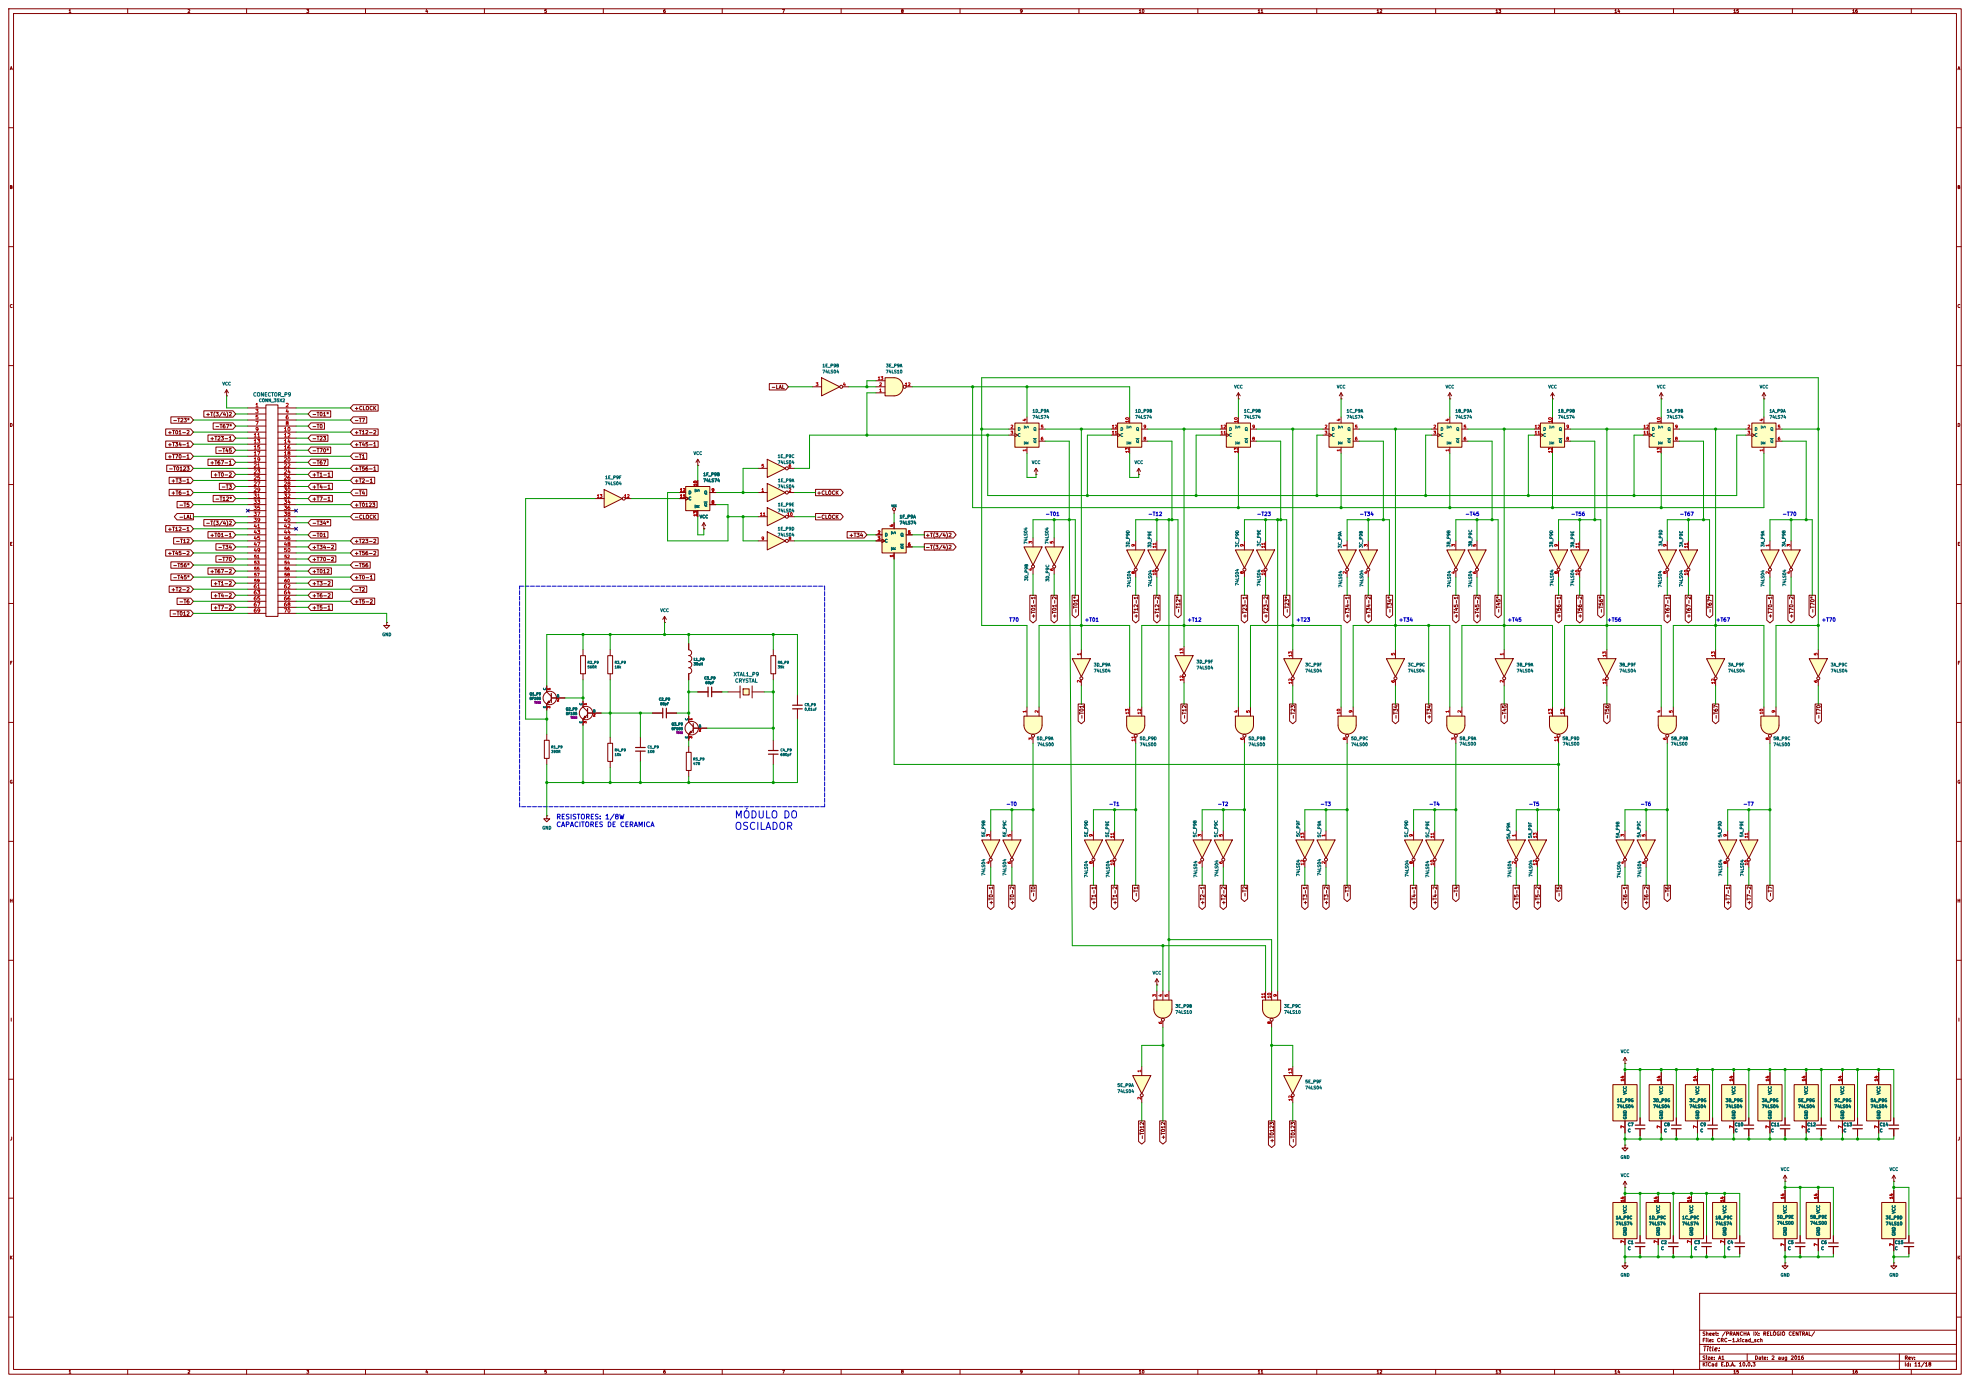
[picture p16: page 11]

Sheet: /PRANCHA IX: RELÓGIO CENTRAL/ 12 13

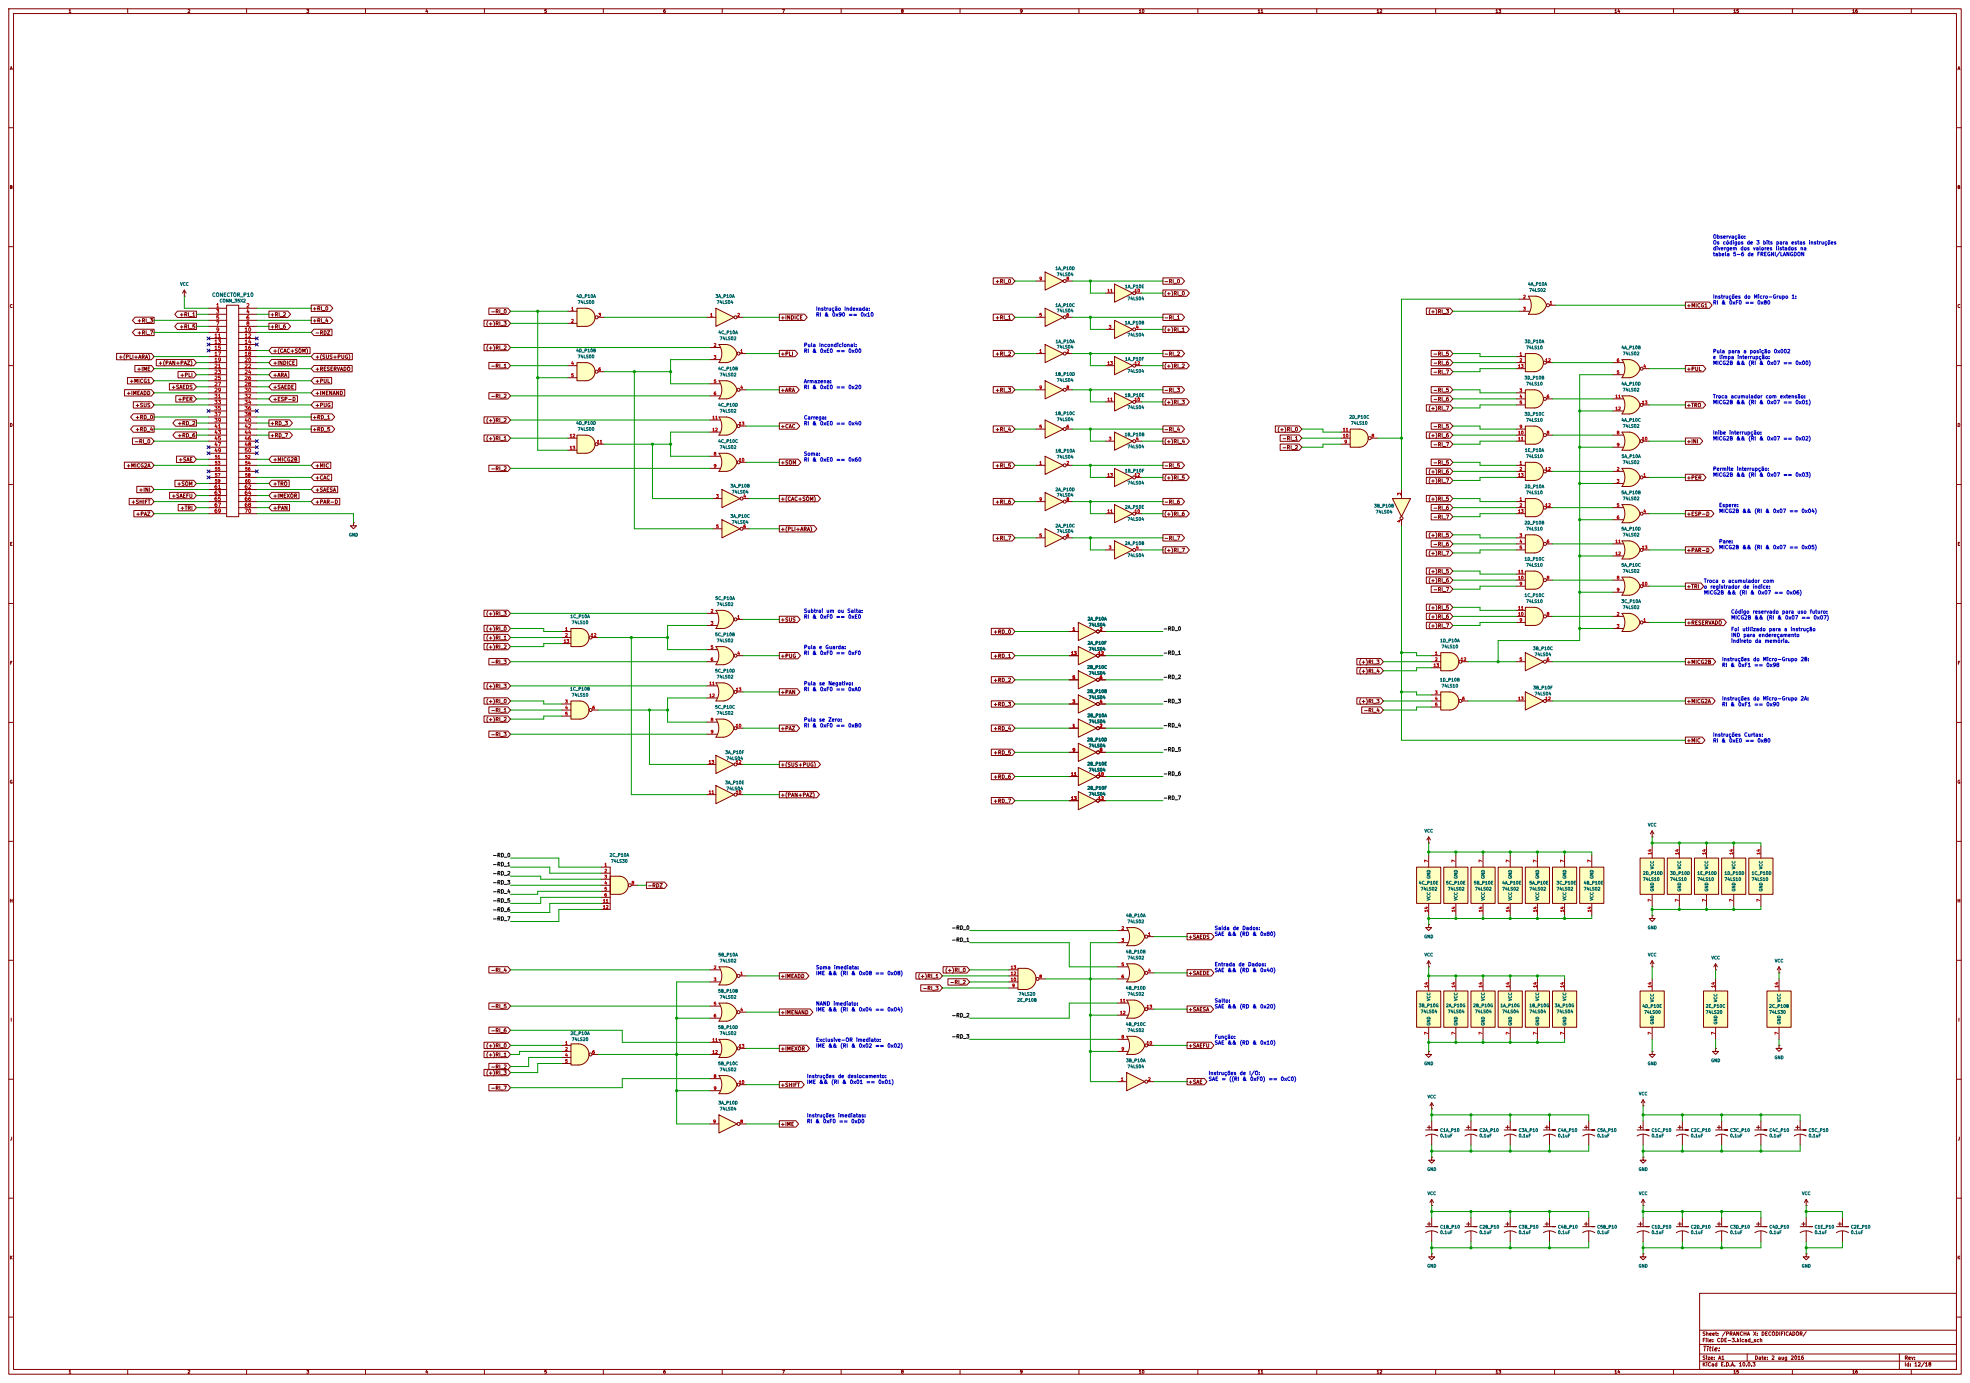
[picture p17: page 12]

Observação:
Os códigos de 3 bits para estas instruções
divergem dos valores listados na
tabela 5-6 de FREGNI/LANGDON

Instruções do Micro-Grupo 1:

Troca acumulador com extensão:
MICG2B && (RI & 0x07 == 0x01)

Subtrai um ou Salta:

Código reservado para uso futuro:
MICG2B && (RI & 0x07 == 0x07)

Foi utilizado para a instrução
IND para endereçamento
indireto da memória.

Instruções do Micro-Grupo 2B:

Instruções do Micro-Grupo 2A:


Sheet: /PRANCHA XI: CONTROLE DE ESTADO/
File: CCE-2.kicad_sch


Precisamos revisar essa parte
Há alguns chutes aqui sobre qual é a
forma correta de se interligar esses chips expansores.

Sheet: /PRANCHA XII: PLACA CONTROLE 1/ GND

13


-CF5 = -F2.INDICE.(CAC+SOM+PLI+ARA) VCC1B_P13C

INDICE.(CAC+SOM+PLI+ARA)

-(CAC+SOM+PLI+ARA)

Sheet: /PRANCHA XIII: PLACA SINAIS CONTROLE/
File: CT2-5.kicad_sch


Sheet: /PRANCHA XIV: PLACA DE CONTROLE/
File: CT3-6.kicad_sch


(!) O esquema original indica 1A2
(que corresponde a -AC_0), mas ao mesmo tempo

TODO: We may need to
also provide +ACN signal.

chama esse sinal de -ACN

O esquemático original
não identifica qual CI nem quais pinos são usados

para essa porta NOT.

(!) Essa porta gera o sinal -RI_7.
Entretanto esse sinal não é usado nesta placa.
Portanto, a porta NOT da unidade F da
pastilha 3A não é realmente necessária.

Sheet: /PRANCHA XV: SINAIS DE CONTROLE/
File: CT4-7.kicad_sch


+(PARTIDA.(-RODA).(MP+CP))

Projeto: Edson Fregni
Sinais de Controle
Computador de Controle - Patinho Feio
EPUSP LSD
Sheet: /PRANCHA XVI: SINAIS DE CONTROLE/
File: CT5-8.kicad_sch
Title: PRANCHA XVI

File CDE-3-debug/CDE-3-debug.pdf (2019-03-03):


File: CDE-3-debug.sch Sheet: /





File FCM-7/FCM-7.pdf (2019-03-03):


Id: 1/1 Title: File: FCM-7.sch Sheet: /

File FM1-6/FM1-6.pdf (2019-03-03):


Id: 1/1 Title: MAIS UM E PORTA DE SELEÇÃO

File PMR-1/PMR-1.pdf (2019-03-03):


Id: 1/1 Title: File: PMR-1.sch Sheet: / 1

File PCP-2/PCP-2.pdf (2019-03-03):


Id: 1/1 Title: File: PCP-2.sch Sheet: / 1

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

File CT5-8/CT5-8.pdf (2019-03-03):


Re-desenho: Felipe Sanches
Computador de Controle - Patinho Feio Sinais de Controle Projeto: Edson Fregni

Id: 1/1 Title: PRANCHA XVI File: CT5-8.sch Sheet: / EPUSP LSD

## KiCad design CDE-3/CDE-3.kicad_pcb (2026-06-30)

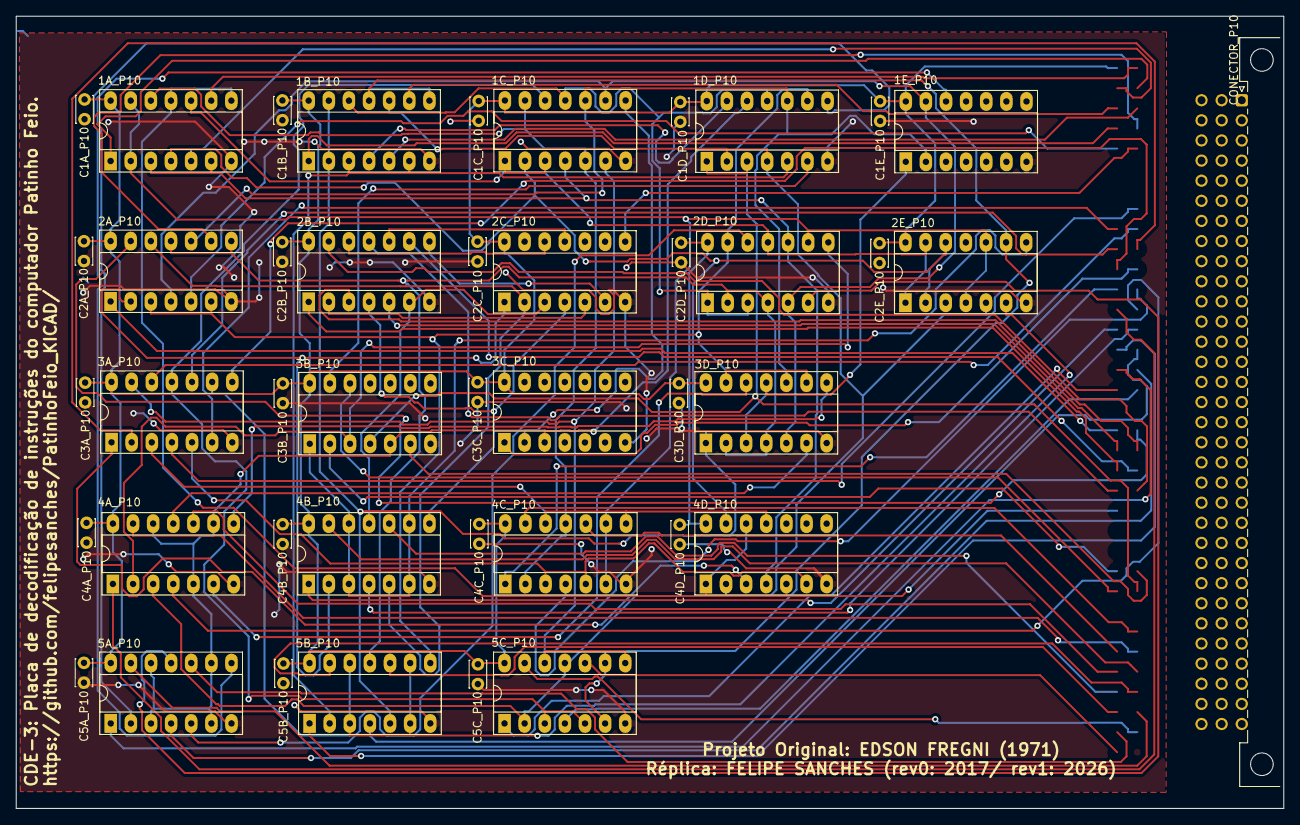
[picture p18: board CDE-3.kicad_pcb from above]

Board: 2 copper layers, 160.0 x 100.0 mm, 43 parts (0 on the bottom side), 96 nets.

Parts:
1A_P10, 1B_P10, 2A_P10, 2B_P10, 3A_P10, 3B_P10: 74HC04; DIP-14_W7.62mm_Socket_LongPads
1C_P10, 1D_P10, 1E_P10, 2D_P10, 3D_P10: 74LS10; DIP-14_W7.62mm_Socket_LongPads
2C_P10: 74LS30; DIP-14_W7.62mm_Socket_LongPads
2E_P10: 74LS13; DIP-14_W7.62mm_Socket_LongPads
3C_P10, 4A_P10, 4B_P10, 4C_P10, 5A_P10, 5B_P10, 5C_P10: 7402; DIP-14_W7.62mm_Socket_LongPads
4D_P10: 7400; DIP-14_W7.62mm_Socket_LongPads
C1A_P10, C1B_P10, C1C_P10, C1D_P10, C1E_P10, C2A_P10, C2B_P10, C2C_P10, C2D_P10, C2E_P10, C3A_P10, C3B_P10, C3C_P10, C3D_P10, C4A_P10, C4B_P10, C4C_P10, C4D_P10, C5A_P10, C5B_P10, C5C_P10: 0.1uF; C_Disc_D3.4mm_W2.1mm_P2.50mm
CONECTOR_P10: CONN_35X2; DIN41612_C_3x32_Male_Horizontal_THT

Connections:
(+)RI_0: 1A_P10.10, 1C_P10.1, 1C_P10.3, 2D_P10.11, 2E_P10.1, 2E_P10.13
(+)RI_1: 1A_P10.4, 1C_P10.2, 2E_P10.2, 2E_P10.12, 4D_P10.13
(+)RI_2: 1A_P10.12, 1C_P10.5, 1C_P10.13, 4C_P10.2, 4C_P10.11
(+)RI_3: 1B_P10.10, 1D_P10.2, 1D_P10.4, 2E_P10.5, 4A_P10.3, 4D_P10.2, 5C_P10.2, 5C_P10.11
(+)RI_4: 1B_P10.4, 1D_P10.13
(+)RI_5: 1B_P10.12, 1C_P10.11, 1D_P10.11, 2D_P10.1, 2D_P10.3
(+)RI_6: 1C_P10.10, 1D_P10.10, 1E_P10.2, 2A_P10.10, 3D_P10.10
(+)RI_7: 1C_P10.9, 1E_P10.13, 2A_P10.4, 2D_P10.5, 3D_P10.5
+(CAC+SOM): 3A_P10.4, CONECTOR_P10.a20
+(PAN+PAZ): 3A_P10.10, CONECTOR_P10.a16
+(PLI+ARA): 3A_P10.6, CONECTOR_P10.a18
+(SUS+PUG): 3A_P10.12, CONECTOR_P10.a17
+ARA: 4C_P10.4, CONECTOR_P10.a8
+CAC: 4C_P10.13, CONECTOR_P10.b12
+ESP-D: 5A_P10.4, CONECTOR_P10.a32
+IME: 3A_P10.8, CONECTOR_P10.a29
+IMEADD: 5B_P10.1, CONECTOR_P10.c13
+IMENAND: 5B_P10.4, CONECTOR_P10.a7
+IMEXOR: 5B_P10.13, CONECTOR_P10.c7
+INDICE: 3A_P10.2, CONECTOR_P10.a15
+INI: 4A_P10.10, CONECTOR_P10.c10
+MIC: 1D_P10.1, 1D_P10.3, 3B_P10.4, CONECTOR_P10.c4
+MICG1: 4A_P10.1, CONECTOR_P10.a11
+MICG2A: 3B_P10.12, CONECTOR_P10.b26
+MICG2B: 3B_P10.6, CONECTOR_P10.a19
+PAN: 5C_P10.13, CONECTOR_P10.c21
+PAR-D: 5A_P10.13, CONECTOR_P10.b17
+PAZ: 5C_P10.10, CONECTOR_P10.b11
+PER: 5A_P10.1, CONECTOR_P10.c31
+PLI: 4C_P10.1, CONECTOR_P10.b31
+PUG: 5C_P10.4, CONECTOR_P10.a13
+PUL: 4A_P10.4, CONECTOR_P10.a10
+RD_0: 2A_P10.1, CONECTOR_P10.a9
+RD_1: 2A_P10.13, CONECTOR_P10.b14
+RD_2: 2B_P10.5, CONECTOR_P10.a4
+RD_3: 2B_P10.3, CONECTOR_P10.a3
+RD_4: 2B_P10.1, CONECTOR_P10.b25
+RD_5: 2B_P10.9, CONECTOR_P10.c5
+RD_6: 2B_P10.11, CONECTOR_P10.b10
+RD_7: 2B_P10.13, CONECTOR_P10.b6
+RESERVADO: 3C_P10.1, CONECTOR_P10.a28
+RI_0: 1A_P10.9, CONECTOR_P10.a2
+RI_1: 1A_P10.5, CONECTOR_P10.b1
+RI_2: 1A_P10.1, CONECTOR_P10.b2
+RI_3: 1B_P10.9, CONECTOR_P10.c1
+RI_4: 1B_P10.5, CONECTOR_P10.c2
+RI_5: 1B_P10.1, CONECTOR_P10.a25
+RI_6: 2A_P10.9, CONECTOR_P10.b19
+RI_7: 2A_P10.5, CONECTOR_P10.b16
+SAE: 3B_P10.2, CONECTOR_P10.a31
+SAEDE: 4B_P10.4, CONECTOR_P10.b28
+SAEDS: 4B_P10.1, CONECTOR_P10.b32
+SAEFU: 4B_P10.10, CONECTOR_P10.c8
+SAESA: 4B_P10.13, CONECTOR_P10.c9
+SHIFT: 5B_P10.10, CONECTOR_P10.c14
+SOM: 4C_P10.10, CONECTOR_P10.c12
+SUS: 5C_P10.1, CONECTOR_P10.b20
+TRI: 5A_P10.10, CONECTOR_P10.b18
+TRO: 4A_P10.13, CONECTOR_P10.c11
-RDZ: 2C_P10.8, CONECTOR_P10.b15
-RD_0: 2A_P10.2, 2C_P10.1, 4B_P10.2
-RD_1: 2A_P10.12, 2C_P10.2, 4B_P10.5
-RD_2: 2B_P10.6, 2C_P10.3, 4B_P10.11
-RD_3: 2B_P10.4, 2C_P10.4, 4B_P10.8
-RD_4: 2B_P10.2, 2C_P10.5
-RD_5: 2B_P10.8, 2C_P10.6
-RD_6: 2B_P10.10, 2C_P10.11
-RD_7: 2B_P10.12, 2C_P10.12
-RI_0: 1A_P10.8, 1A_P10.11, 4D_P10.1, 4D_P10.5, 4D_P10.12, CONECTOR_P10.b13
-RI_1: 1A_P10.3, 1A_P10.6, 1C_P10.4, 2D_P10.10, 4D_P10.4
-RI_2: 1A_P10.2, 1A_P10.13, 2D_P10.9, 2E_P10.4, 2E_P10.10, 4C_P10.6, 4C_P10.9
-RI_3: 1B_P10.8, 1B_P10.11, 2E_P10.9, 5C_P10.6, 5C_P10.9
-RI_4: 1B_P10.3, 1B_P10.6, 1D_P10.5, 5B_P10.2
-RI_5: 1B_P10.2, 1B_P10.13, 1E_P10.1, 3D_P10.1, 3D_P10.3, 3D_P10.11, 5B_P10.5
-RI_6: 2A_P10.8, 2A_P10.11, 2D_P10.2, 2D_P10.4, 3D_P10.2, 3D_P10.4, 5B_P10.11
-RI_7: 1D_P10.9, 2A_P10.3, 2A_P10.6, 2D_P10.13, 3D_P10.9, 3D_P10.13, 5B_P10.8
GND: 1A_P10.7, 1B_P10.7, 1C_P10.7, 1D_P10.7, 1E_P10.7, 2A_P10.7, 2B_P10.7, 2C_P10.7, 2D_P10.7, 2E_P10.7, 3A_P10.7, 3B_P10.7, 3C_P10.7, 3D_P10.7, 4A_P10.7, 4B_P10.7, 4C_P10.7, 4D_P10.7, 5A_P10.7, 5B_P10.7, 5C_P10.7, C1A_P10.2, C1B_P10.2, C1C_P10.2, C1D_P10.2, C1E_P10.2, C2A_P10.2, C2B_P10.2, C2C_P10.2, C2D_P10.2, C2E_P10.2, C3A_P10.2, C3B_P10.2, C3C_P10.2, C3D_P10.2, C4A_P10.2, C4B_P10.2, C4C_P10.2, C4D_P10.2, C5A_P10.2, C5B_P10.2, C5C_P10.2, CONECTOR_P10.c22
unnamed: 1C_P10.6, 3A_P10.13, 5C_P10.8, 5C_P10.12
unnamed: 1C_P10.8, 3C_P10.2
unnamed: 1C_P10.12, 3A_P10.11, 5C_P10.3, 5C_P10.5
unnamed: 1D_P10.6, 3B_P10.13
unnamed: 1D_P10.8, 5A_P10.8
unnamed: 1D_P10.12, 3B_P10.5, 3C_P10.3, 4A_P10.5, 4A_P10.9, 4A_P10.12, 5A_P10.3, 5A_P10.6, 5A_P10.9, 5A_P10.12
unnamed: 1E_P10.12, 5A_P10.2
unnamed: 2D_P10.6, 5A_P10.11
unnamed: 2D_P10.8, 3B_P10.3, 4A_P10.2
unnamed: 2D_P10.12, 5A_P10.5
unnamed: 2E_P10.6, 3A_P10.9, 5B_P10.3, 5B_P10.6, 5B_P10.9, 5B_P10.12
unnamed: 2E_P10.8, 3B_P10.1, 4B_P10.3, 4B_P10.6, 4B_P10.9, 4B_P10.12
unnamed: 3A_P10.1, 4D_P10.3
unnamed: 3A_P10.3, 4C_P10.8, 4C_P10.12, 4D_P10.11
unnamed: 3A_P10.5, 4C_P10.3, 4C_P10.5, 4D_P10.6
unnamed: 3D_P10.6, 4A_P10.11
unnamed: 3D_P10.8, 4A_P10.8
unnamed: 3D_P10.12, 4A_P10.6
VCC: 1A_P10.14, 1B_P10.14, 1C_P10.14, 1D_P10.14, 1E_P10.14, 2A_P10.14, 2B_P10.14, 2C_P10.14, 2D_P10.14, 2E_P10.14, 3A_P10.14, 3B_P10.14, 3C_P10.14, 3D_P10.14, 4A_P10.14, 4B_P10.14, 4C_P10.14, 4D_P10.14, 5A_P10.14, 5B_P10.14, 5C_P10.14, C1A_P10.1, C1B_P10.1, C1C_P10.1, C1D_P10.1, C1E_P10.1, C2A_P10.1, C2B_P10.1, C2C_P10.1, C2D_P10.1, C2E_P10.1, C3A_P10.1, C3B_P10.1, C3C_P10.1, C3D_P10.1, C4A_P10.1, C4B_P10.1, C4C_P10.1, C4D_P10.1, C5A_P10.1, C5B_P10.1, C5C_P10.1, CONECTOR_P10.a1

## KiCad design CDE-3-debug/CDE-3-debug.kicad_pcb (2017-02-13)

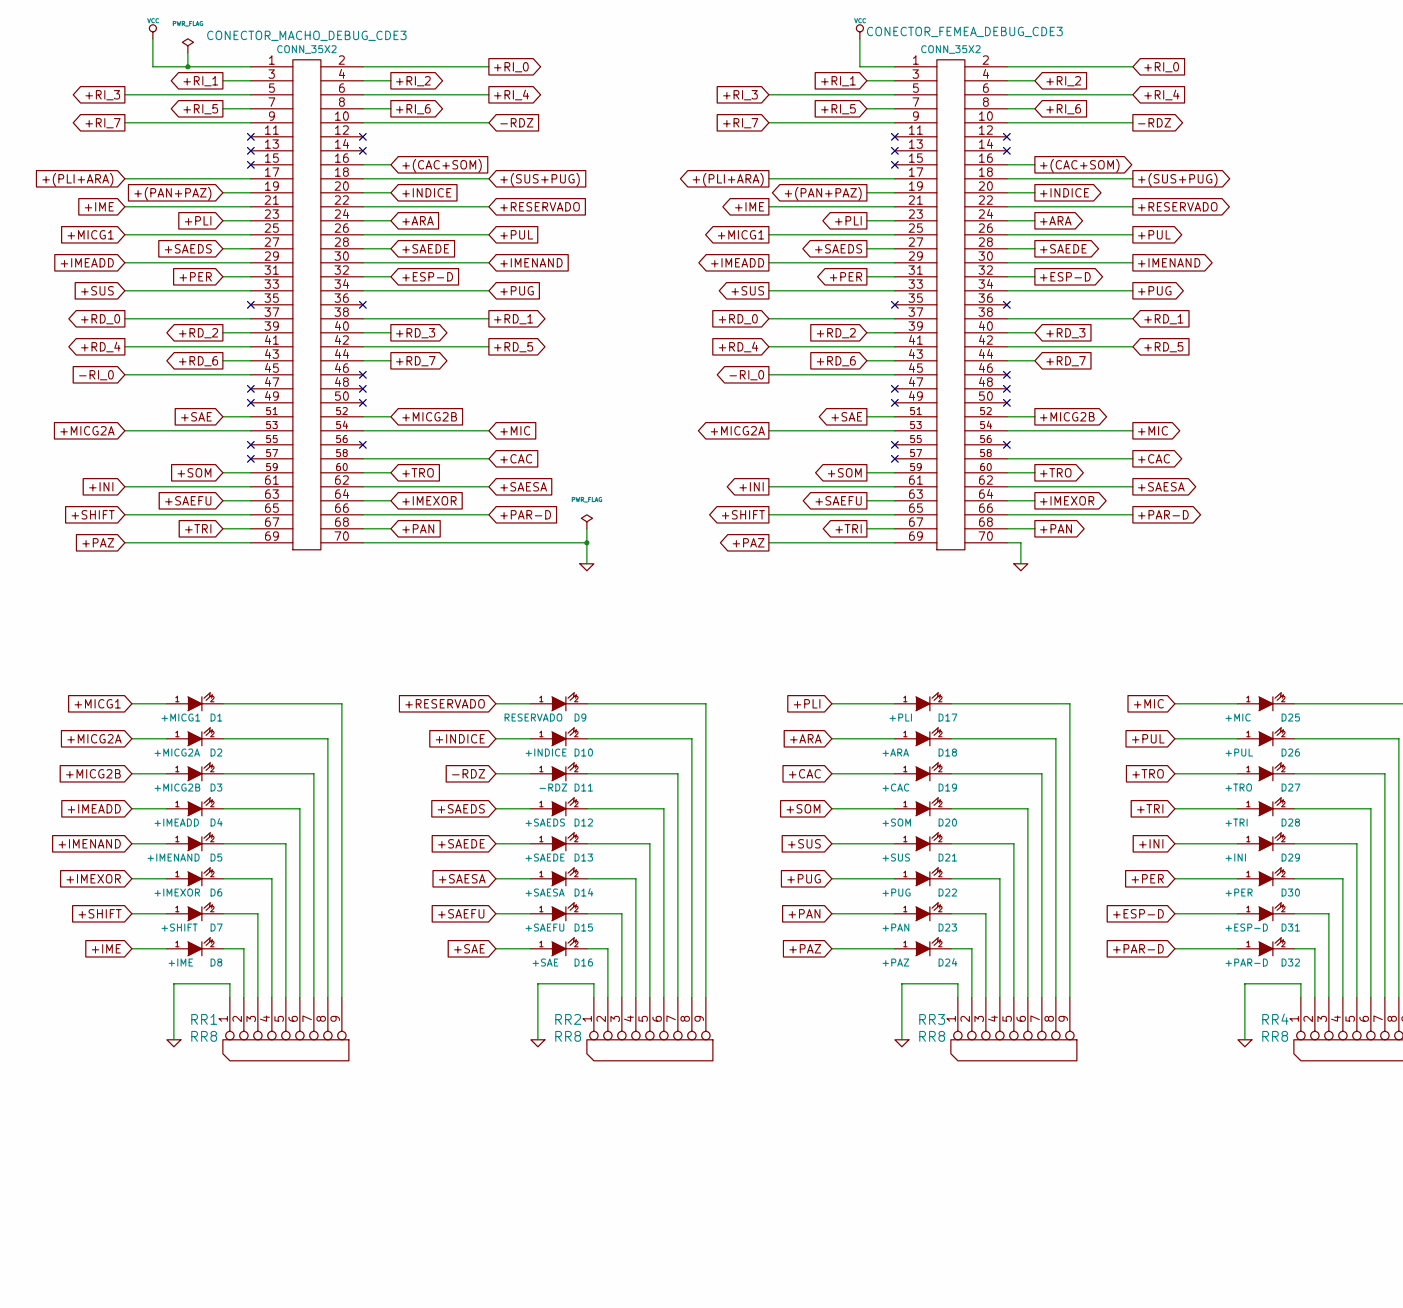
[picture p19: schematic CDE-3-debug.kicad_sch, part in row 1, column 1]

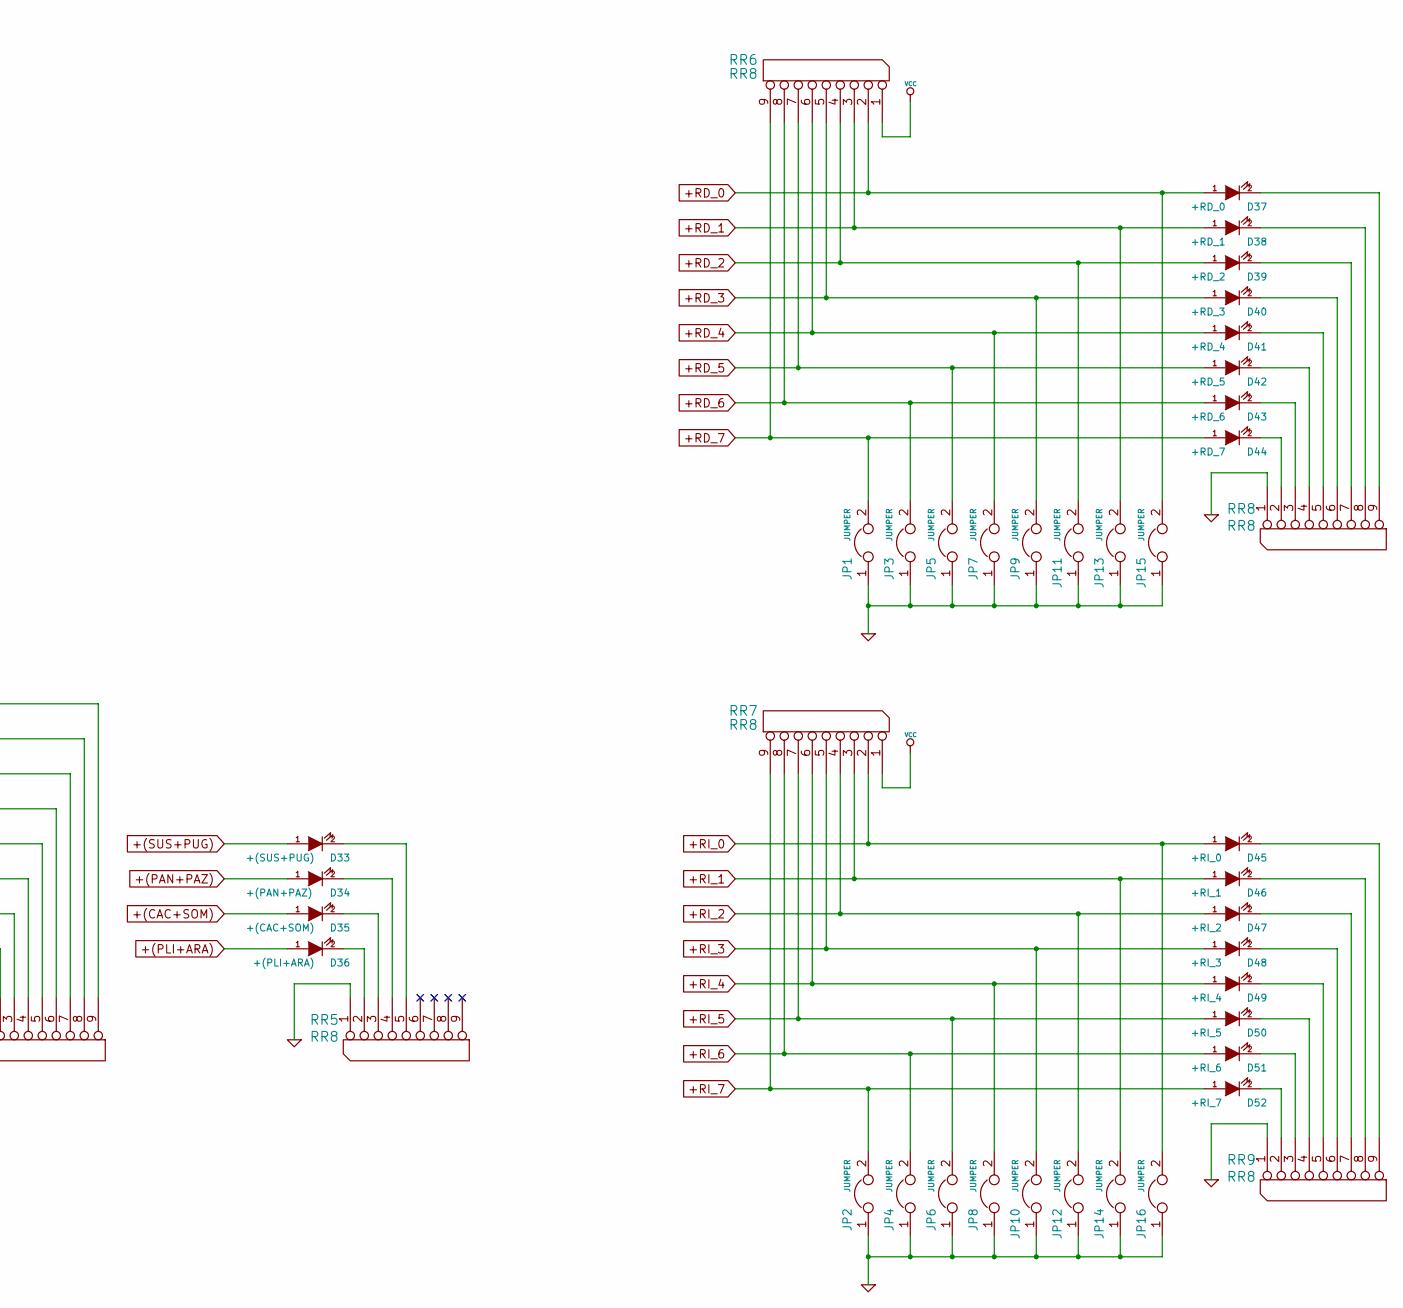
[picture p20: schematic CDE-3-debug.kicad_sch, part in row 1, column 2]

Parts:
CONECTOR_FEMEA_DEBUG_CDE3: CONN_35X2; Pin_Header_Angled_2x35_Pitch2.54mm
CONECTOR_MACHO_DEBUG_CDE3: CONN_35X2; Pin_Header_Angled_2x35_Pitch2.54mm
D1: +MICG1; LED_D3.0mm
D2: +MICG2A; LED_D3.0mm
D3: +MICG2B; LED_D3.0mm
D4: +IMEADD; LED_D3.0mm
D5: +IMENAND; LED_D3.0mm
D6: +IMEXOR; LED_D3.0mm
D7: +SHIFT; LED_D3.0mm
D8: +IME; LED_D3.0mm
D9: RESERVADO; LED_D3.0mm
D10: +INDICE; LED_D3.0mm
D11: -RDZ; LED_D3.0mm
D12: +SAEDS; LED_D3.0mm
D13: +SAEDE; LED_D3.0mm
D14: +SAESA; LED_D3.0mm
D15: +SAEFU; LED_D3.0mm
D16: +SAE; LED_D3.0mm
D17: +PLI; LED_D3.0mm
D18: +ARA; LED_D3.0mm
D19: +CAC; LED_D3.0mm
D20: +SOM; LED_D3.0mm
D21: +SUS; LED_D3.0mm
D22: +PUG; LED_D3.0mm
D23: +PAN; LED_D3.0mm
D24: +PAZ; LED_D3.0mm
D25: +MIC; LED_D3.0mm
D26: +PUL; LED_D3.0mm
D27: +TRO; LED_D3.0mm
D28: +TRI; LED_D3.0mm
D29: +INI; LED_D3.0mm
D30: +PER; LED_D3.0mm
D31: +ESP-D; LED_D3.0mm
D32: +PAR-D; LED_D3.0mm
D33: +(SUS+PUG); LED_D3.0mm
D34: +(PAN+PAZ); LED_D3.0mm
D35: +(CAC+SOM); LED_D3.0mm
D36: +(PLI+ARA); LED_D3.0mm
D37: +RD_0; LED_D3.0mm
D38: +RD_1; LED_D3.0mm
D39: +RD_2; LED_D3.0mm
D40: +RD_3; LED_D3.0mm
D41: +RD_4; LED_D3.0mm
D42: +RD_5; LED_D3.0mm
D43: +RD_6; LED_D3.0mm
D44: +RD_7; LED_D3.0mm
D45: +RI_0; LED_D3.0mm
D46: +RI_1; LED_D3.0mm
D47: +RI_2; LED_D3.0mm
D48: +RI_3; LED_D3.0mm
D49: +RI_4; LED_D3.0mm
D50: +RI_5; LED_D3.0mm
D51: +RI_6; LED_D3.0mm
D52: +RI_7; LED_D3.0mm
JP1, JP2, JP3, JP4, JP5, JP6, JP7, JP8, JP9, JP10, JP11, JP12, JP13, JP14, JP15, JP16: JUMPER; Pin_Header_Straight_1x02_Pitch2.54mm
RR1, RR2, RR3, RR4, RR5, RR6, RR7, RR8, RR9: RR8; R_Array_SIP9

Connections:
+(CAC+SOM): CONECTOR_FEMEA_DEBUG_CDE3.16, CONECTOR_MACHO_DEBUG_CDE3.16, D35.1 (A)
+(PAN+PAZ): CONECTOR_FEMEA_DEBUG_CDE3.19, CONECTOR_MACHO_DEBUG_CDE3.19, D34.1 (A)
+(PLI+ARA): CONECTOR_FEMEA_DEBUG_CDE3.17, CONECTOR_MACHO_DEBUG_CDE3.17, D36.1 (A)
+(SUS+PUG): CONECTOR_FEMEA_DEBUG_CDE3.18, CONECTOR_MACHO_DEBUG_CDE3.18, D33.1 (A)
+ARA: CONECTOR_FEMEA_DEBUG_CDE3.24, CONECTOR_MACHO_DEBUG_CDE3.24, D18.1 (A)
+CAC: CONECTOR_FEMEA_DEBUG_CDE3.58, CONECTOR_MACHO_DEBUG_CDE3.58, D19.1 (A)
+ESP-D: CONECTOR_FEMEA_DEBUG_CDE3.32, CONECTOR_MACHO_DEBUG_CDE3.32, D31.1 (A)
+IME: CONECTOR_FEMEA_DEBUG_CDE3.21, CONECTOR_MACHO_DEBUG_CDE3.21, D8.1 (A)
+IMEADD: CONECTOR_FEMEA_DEBUG_CDE3.29, CONECTOR_MACHO_DEBUG_CDE3.29, D4.1 (A)
+IMENAND: CONECTOR_FEMEA_DEBUG_CDE3.30, CONECTOR_MACHO_DEBUG_CDE3.30, D5.1 (A)
+IMEXOR: CONECTOR_FEMEA_DEBUG_CDE3.64, CONECTOR_MACHO_DEBUG_CDE3.64, D6.1 (A)
+INDICE: CONECTOR_FEMEA_DEBUG_CDE3.20, CONECTOR_MACHO_DEBUG_CDE3.20, D10.1 (A)
+INI: CONECTOR_FEMEA_DEBUG_CDE3.61, CONECTOR_MACHO_DEBUG_CDE3.61, D29.1 (A)
+MIC: CONECTOR_FEMEA_DEBUG_CDE3.54, CONECTOR_MACHO_DEBUG_CDE3.54, D25.1 (A)
+MICG1: CONECTOR_FEMEA_DEBUG_CDE3.25, CONECTOR_MACHO_DEBUG_CDE3.25, D1.1 (A)
+MICG2A: CONECTOR_FEMEA_DEBUG_CDE3.53, CONECTOR_MACHO_DEBUG_CDE3.53, D2.1 (A)
+MICG2B: CONECTOR_FEMEA_DEBUG_CDE3.52, CONECTOR_MACHO_DEBUG_CDE3.52, D3.1 (A)
+PAN: CONECTOR_FEMEA_DEBUG_CDE3.68, CONECTOR_MACHO_DEBUG_CDE3.68, D23.1 (A)
+PAR-D: CONECTOR_FEMEA_DEBUG_CDE3.66, CONECTOR_MACHO_DEBUG_CDE3.66, D32.1 (A)
+PAZ: CONECTOR_FEMEA_DEBUG_CDE3.69, CONECTOR_MACHO_DEBUG_CDE3.69, D24.1 (A)
+PER: CONECTOR_FEMEA_DEBUG_CDE3.31, CONECTOR_MACHO_DEBUG_CDE3.31, D30.1 (A)
+PLI: CONECTOR_FEMEA_DEBUG_CDE3.23, CONECTOR_MACHO_DEBUG_CDE3.23, D17.1 (A)
+PUG: CONECTOR_FEMEA_DEBUG_CDE3.34, CONECTOR_MACHO_DEBUG_CDE3.34, D22.1 (A)
+PUL: CONECTOR_FEMEA_DEBUG_CDE3.26, CONECTOR_MACHO_DEBUG_CDE3.26, D26.1 (A)
+RD_0: CONECTOR_FEMEA_DEBUG_CDE3.37, CONECTOR_MACHO_DEBUG_CDE3.37, D37.1 (A), JP15.2, RR6.2
+RD_1: CONECTOR_FEMEA_DEBUG_CDE3.38, CONECTOR_MACHO_DEBUG_CDE3.38, D38.1 (A), JP13.2, RR6.3
+RD_2: CONECTOR_FEMEA_DEBUG_CDE3.39, CONECTOR_MACHO_DEBUG_CDE3.39, D39.1 (A), JP11.2, RR6.4
+RD_3: CONECTOR_FEMEA_DEBUG_CDE3.40, CONECTOR_MACHO_DEBUG_CDE3.40, D40.1 (A), JP9.2, RR6.5
+RD_4: CONECTOR_FEMEA_DEBUG_CDE3.41, CONECTOR_MACHO_DEBUG_CDE3.41, D41.1 (A), JP7.2, RR6.6
+RD_5: CONECTOR_FEMEA_DEBUG_CDE3.42, CONECTOR_MACHO_DEBUG_CDE3.42, D42.1 (A), JP5.2, RR6.7
+RD_6: CONECTOR_FEMEA_DEBUG_CDE3.43, CONECTOR_MACHO_DEBUG_CDE3.43, D43.1 (A), JP3.2, RR6.8
+RD_7: CONECTOR_FEMEA_DEBUG_CDE3.44, CONECTOR_MACHO_DEBUG_CDE3.44, D44.1 (A), JP1.2, RR6.9
+RESERVADO: CONECTOR_FEMEA_DEBUG_CDE3.22, CONECTOR_MACHO_DEBUG_CDE3.22, D9.1 (A)
+RI_0: CONECTOR_FEMEA_DEBUG_CDE3.2, CONECTOR_MACHO_DEBUG_CDE3.2, D45.1 (A), JP16.2, RR7.2
+RI_1: CONECTOR_FEMEA_DEBUG_CDE3.3, CONECTOR_MACHO_DEBUG_CDE3.3, D46.1 (A), JP14.2, RR7.3
+RI_2: CONECTOR_FEMEA_DEBUG_CDE3.4, CONECTOR_MACHO_DEBUG_CDE3.4, D47.1 (A), JP12.2, RR7.4
+RI_3: CONECTOR_FEMEA_DEBUG_CDE3.5, CONECTOR_MACHO_DEBUG_CDE3.5, D48.1 (A), JP10.2, RR7.5
+RI_4: CONECTOR_FEMEA_DEBUG_CDE3.6, CONECTOR_MACHO_DEBUG_CDE3.6, D49.1 (A), JP8.2, RR7.6
+RI_5: CONECTOR_FEMEA_DEBUG_CDE3.7, CONECTOR_MACHO_DEBUG_CDE3.7, D50.1 (A), JP6.2, RR7.7
+RI_6: CONECTOR_FEMEA_DEBUG_CDE3.8, CONECTOR_MACHO_DEBUG_CDE3.8, D51.1 (A), JP4.2, RR7.8
+RI_7: CONECTOR_FEMEA_DEBUG_CDE3.9, CONECTOR_MACHO_DEBUG_CDE3.9, D52.1 (A), JP2.2, RR7.9
+SAE: CONECTOR_FEMEA_DEBUG_CDE3.51, CONECTOR_MACHO_DEBUG_CDE3.51, D16.1 (A)
+SAEDE: CONECTOR_FEMEA_DEBUG_CDE3.28, CONECTOR_MACHO_DEBUG_CDE3.28, D13.1 (A)
+SAEDS: CONECTOR_FEMEA_DEBUG_CDE3.27, CONECTOR_MACHO_DEBUG_CDE3.27, D12.1 (A)
+SAEFU: CONECTOR_FEMEA_DEBUG_CDE3.63, CONECTOR_MACHO_DEBUG_CDE3.63, D15.1 (A)
+SAESA: CONECTOR_FEMEA_DEBUG_CDE3.62, CONECTOR_MACHO_DEBUG_CDE3.62, D14.1 (A)
+SHIFT: CONECTOR_FEMEA_DEBUG_CDE3.65, CONECTOR_MACHO_DEBUG_CDE3.65, D7.1 (A)
+SOM: CONECTOR_FEMEA_DEBUG_CDE3.59, CONECTOR_MACHO_DEBUG_CDE3.59, D20.1 (A)
+SUS: CONECTOR_FEMEA_DEBUG_CDE3.33, CONECTOR_MACHO_DEBUG_CDE3.33, D21.1 (A)
+TRI: CONECTOR_FEMEA_DEBUG_CDE3.67, CONECTOR_MACHO_DEBUG_CDE3.67, D28.1 (A)
+TRO: CONECTOR_FEMEA_DEBUG_CDE3.60, CONECTOR_MACHO_DEBUG_CDE3.60, D27.1 (A)
-RDZ: CONECTOR_FEMEA_DEBUG_CDE3.10, CONECTOR_MACHO_DEBUG_CDE3.10, D11.1 (A)
-RI_0: CONECTOR_FEMEA_DEBUG_CDE3.45, CONECTOR_MACHO_DEBUG_CDE3.45
GND: CONECTOR_FEMEA_DEBUG_CDE3.70, CONECTOR_MACHO_DEBUG_CDE3.70, JP1.1, JP2.1, JP3.1, JP4.1, JP5.1, JP6.1, JP7.1, JP8.1, JP9.1, JP10.1, JP11.1, JP12.1, JP13.1, JP14.1, JP15.1, JP16.1, RR1.1 (COM), RR2.1 (COM), RR3.1 (COM), RR4.1 (COM), RR5.1 (COM), RR8.1 (COM), RR9.1 (COM)
unnamed: D1.2 (K), RR1.9
unnamed: D2.2 (K), RR1.8
unnamed: D3.2 (K), RR1.7
unnamed: D4.2 (K), RR1.6
unnamed: D5.2 (K), RR1.5
unnamed: D6.2 (K), RR1.4
unnamed: D7.2 (K), RR1.3
unnamed: D8.2 (K), RR1.2
unnamed: D9.2 (K), RR2.9
unnamed: D10.2 (K), RR2.8
unnamed: D11.2 (K), RR2.7
unnamed: D12.2 (K), RR2.6
unnamed: D13.2 (K), RR2.5
unnamed: D14.2 (K), RR2.4
unnamed: D15.2 (K), RR2.3
unnamed: D16.2 (K), RR2.2
unnamed: D17.2 (K), RR3.9
unnamed: D18.2 (K), RR3.8
unnamed: D19.2 (K), RR3.7
unnamed: D20.2 (K), RR3.6
unnamed: D21.2 (K), RR3.5
unnamed: D22.2 (K), RR3.4
unnamed: D23.2 (K), RR3.3
unnamed: D24.2 (K), RR3.2
unnamed: D25.2 (K), RR4.9
unnamed: D26.2 (K), RR4.8
unnamed: D27.2 (K), RR4.7
unnamed: D28.2 (K), RR4.6
unnamed: D29.2 (K), RR4.5
unnamed: D30.2 (K), RR4.4
unnamed: D31.2 (K), RR4.3
unnamed: D32.2 (K), RR4.2
unnamed: D33.2 (K), RR5.5
unnamed: D34.2 (K), RR5.4
unnamed: D35.2 (K), RR5.3
unnamed: D36.2 (K), RR5.2
unnamed: D37.2 (K), RR8.9
unnamed: D38.2 (K), RR8.8
unnamed: D39.2 (K), RR8.7
unnamed: D40.2 (K), RR8.6
unnamed: D41.2 (K), RR8.5
unnamed: D42.2 (K), RR8.4
unnamed: D43.2 (K), RR8.3
unnamed: D44.2 (K), RR8.2
unnamed: D45.2 (K), RR9.9
unnamed: D46.2 (K), RR9.8
unnamed: D47.2 (K), RR9.7
unnamed: D48.2 (K), RR9.6
unnamed: D49.2 (K), RR9.5
unnamed: D50.2 (K), RR9.4
unnamed: D51.2 (K), RR9.3
unnamed: D52.2 (K), RR9.2
VCC: CONECTOR_FEMEA_DEBUG_CDE3.1, CONECTOR_MACHO_DEBUG_CDE3.1, RR6.1 (COM), RR7.1 (COM)

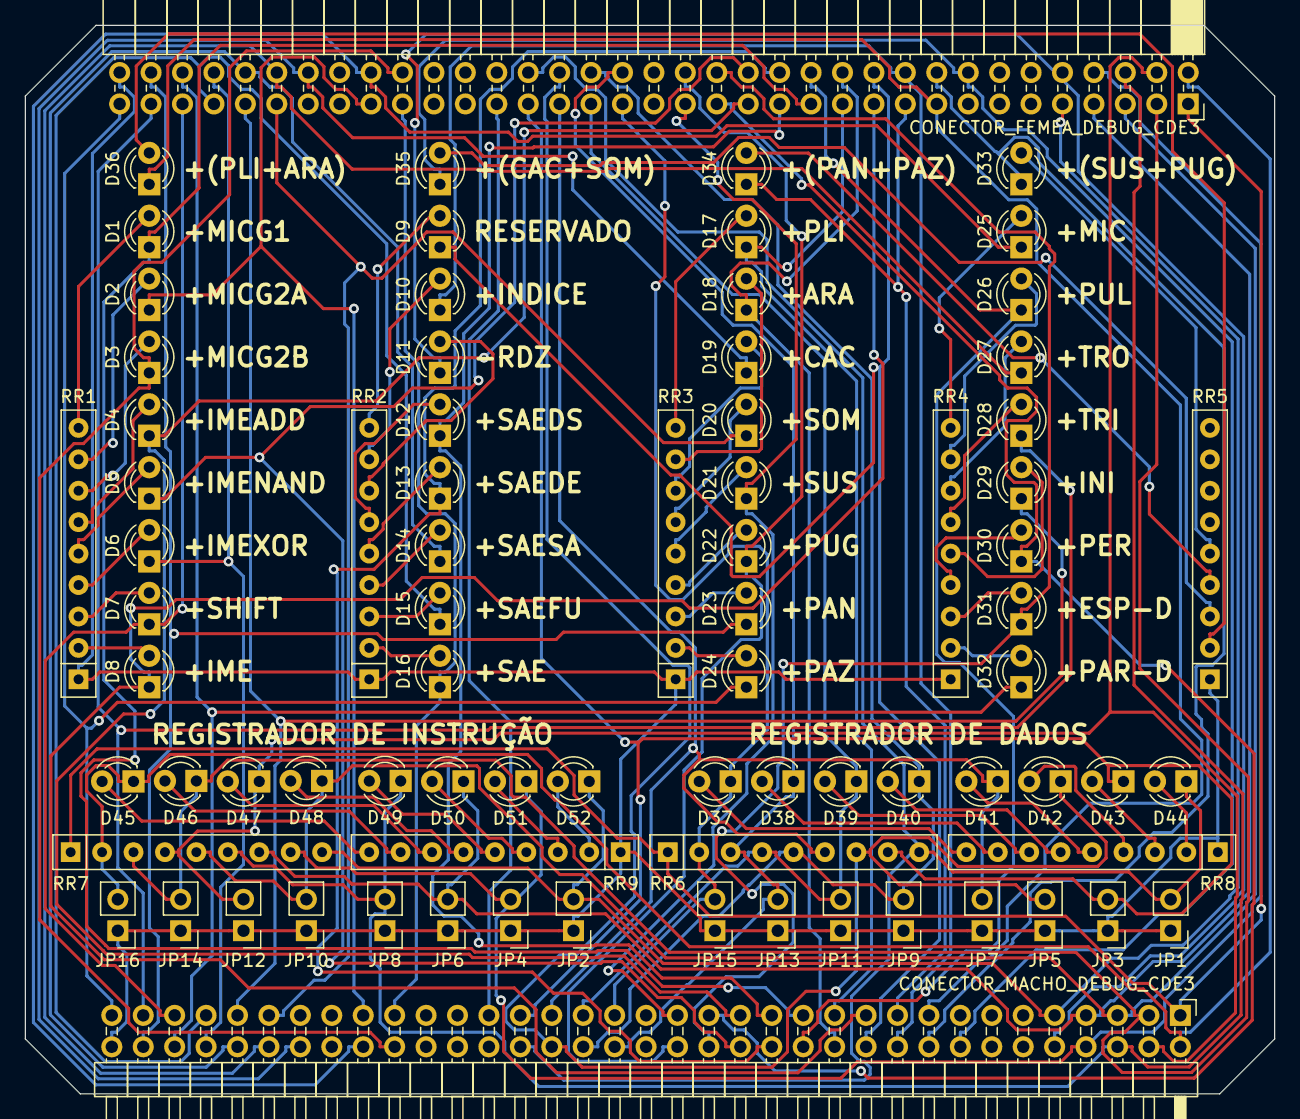
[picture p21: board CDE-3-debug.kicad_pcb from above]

Board: 2 copper layers, 101.0 x 86.4 mm, 79 parts (0 on the bottom side), 107 nets.

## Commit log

2016-06-22 inicio do trabalho de transcrição dos esquematicos da tese do Edson Fregni
    [patinhofeio.sch]
2016-06-23 mudando o esquema de representação dos nomes dos sinais de input e output
    [patinhofeio.sch]
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2016-06-25 finalizando transcrição inicial do circuito da prancha X
    [prancha-X.sch]
2016-06-25 sufixo de prancha pra deixar o ERC feliz :-(
    [prancha-X.sch, prancha-XVI.sch]
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2016-06-28 esquematico da prancha 4 e desenho do componente 7451
    [patinhofeio.sch, prancha-I.sch, prancha-II.sch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]
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2017-01-06 transcricao de mais um pouco do esquematico (prancha XIV)
    [prancha-XIV.sch]
2017-01-06 finalizei a transcrição da prancha XIV! E gerei um PDF dos esquemáticos (incompletos).
    [patinhofeio.sch, prancha-XIV.sch]
2017-01-06 revisei referencias e pinos dos chips de um pedaco incompleto de transcricao da prancha XIII
    [prancha-XIII.sch]
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2017-01-08 mais um pouco de transcrição, agora na prancha 15
    [patinhofeio.sch, prancha-XV.sch]
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2017-01-10 finalizada a transcrição da prancha 15! (PDF atualizado)
    [prancha-XV.sch]
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2017-01-11 parte do esquemático da prancha 11 (essa prancha é cheia de truquezinhos de projeto e a notação é ambígua e aparentemente contém também diversos error no desenho. Vai ser um desafio interessante desv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
    [patinhofeio.sch, prancha-XI.sch]
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2017-01-13 Reorganização geral da folha principal do esquemático adicionando informações com base no texto da tese de mestrado do professor Edson Fregni (Projeto Lógico da Unidade de Controle de Um Minicomputat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
    [patinhofeio.sch]
2017-01-16 conector de 70 pinos para a interconexão das placas e término do desenho da prancha 5.
    [patinhofeio.sch, prancha-I.sch, prancha-II.sch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]
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2017-01-17 vários trechos de transcrição e, em particular, término do conector dos sinais da prancha 11.
    [prancha-X.sch, prancha-XI.sch]
2017-01-17 numerando todas referencias e corrigindo erros de referencias duplas ou pacotes inconsistentes
    [prancha-I.sch, prancha-II.sch, prancha-III.sch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]
2017-01-17 wip. acho que preciso separar cada uma das pranchas em um projeto de PCB independente.
    [prancha-IX.sch, prancha-XIII.sch, prancha-XIV.sch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]
2017-01-17 Migrando esquemático da placa CDE-3 (decodificador) para novo projeto.
    [CDE-3.sch]
2017-01-17 Migrando esquemático da prancha 9 (placa CRC-1 - relógio central) para projeto novo.
    [CRC-1.kicad_pcb, CRC-1.sch]
2017-01-17 Migrando esquemático (incompleto) da prancha 11 (placa CCE-2 - Controle de Estado) para um projeto novo.
    [CCE-2.kicad_pcb, CCE-2.sch]
2017-01-17 removendo prancha 9 (que já foi migrada para projeto de placa independente)
    [prancha-IX.sch]
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2017-01-17 movendo todos arquivos de pranchas para os diretorios onde teremos novos projetos individuais
    [prancha-I.sch, prancha-II.sch, prancha-III.sch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]
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2017-01-17 criando novos projetos individuais para todas as outras pranchas que ainda faltavam serem migradas.
    [FAC-5.kicad_pcb, FAC-5.sch, FCM-7.kicad_pcb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]
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2017-01-17 terminando de corrigir todos os error do DRC no esquemático CT5-8
    [CT5-8.sch]
2017-01-18 finalizada transcrição do esquemático PMR-1 (Painel - Mostra Registradores)
    [PMR-1.sch]
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2017-01-21 finalizado o desenho do esquematico da placa CT2-5
    [CT2-5.sch]
2017-01-21 terminei a transcrição do esquema da placa CT3-6
    [CT3-6.sch]
2017-01-21 terminei a transcrição do esquema da placa CT4-7
    [CT4-7.sch]
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2017-02-04 limpando a PCB e preparando os planos de terra e as linhas de corte da borda para re-executar o auto-router. Validei também os critérios de largura e espaçamento de trilhas e diametro de vias para es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
    [CDE-3.kicad_pcb]
2017-02-04 tentando novamente com uma área d epcb um pouco maior...
    [CDE-3.dsn, CDE-3.kicad_pcb]
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2017-02-04 CDE-3: adicinando texto descritico à camada de silk superior
    [CDE-3.kicad_pcb]
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2018-01-10 Corrigindo erros da rev.A (Eu acabei esquecendo de distribuir o sinal de GND de todos os CIs :-P)
    [CDE-3.kicad_pcb]
2018-02-15 update schematics symbols on CDE-3 after installing kicad compiled from today's git master source code.
    [CDE-3.sch]
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2019-03-03 arquivos auxiliares das placas CDE-3 e CDE-3-debug que estavam soltos
    na minha cópia local.
    [CDE-3-2018-02-15-09-40-38.sch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]
2019-03-03 placa CRC-1: remapping de símbolos após atualização para versao mais nova do KICAD
    [CRC-1-2019-03-03-05-49-53.sch, CRC-1.sch]
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2025-07-24 "rescuing" symbols and updating schematics files.
    I am now using KICAD version 9.0.2+dfsg-1 installed as a package from Debian 13.
    [CCE-2.kicad_sch, CDE-3-debug.kicad_sch, CDE-3.kicad_sch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]
2025-07-24 I believe I can now delete the old version of the schematics files (*.sch)
    Because now we'll use the new format (*.kicad_sch)
    [CCE-2.sch, CDE-3-debug.sch, CDE-3.sch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]
2025-07-24 fix references to schematics from the main schem
    [patinhofeio.sch]
2025-07-25 fix main schematics sheet and its hierarchical references to the other ones
    [CCE-2.kicad_sch, CDE-3.kicad_sch, CRC-1.kicad_sch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]
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2025-07-31 initial work on schematics for a backplane to which all boards will be attached.
    [CRC-1.kicad_sch, CT4-7.kicad_sch, FAC-5.kicad_sch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]
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2026-06-29 first review and many fixes to FS1-3 board
    [FS1-3.kicad_sch]
2026-06-29 I've started modifying the CDE-3 board to use DIN-41612 connectors. This is still wip! I'll get back to it once I receive some sample parts by mail.
    [CDE-3.kicad_pcb, CDE-3.kicad_sch]
2026-06-29 These are updated files after I loaded the project on a new version of KICAD
    [CCE-2.kicad_sch, CRC-1.kicad_sch, CT1-4.kicad_sch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]
2026-06-29 add connectors for FS1_3 and FS2_4 to the backplane
    [backplane.kicad_sch]
2026-06-29 adding references to a couple NOT gates that are not annotated in the original schematics.
    [FS1-3.kicad_sch]
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2026-07-01 Some initial fixing of ERC errors.
    [CCE-2.kicad_sch, CDE-3.kicad_sch, CRC-1.kicad_sch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]
2026-07-01 addressing a few more ERC errors
    [CRC-1.kicad_sch, CT1-4.kicad_sch, CT2-5.kicad_sch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]
2026-07-03 fix a whole bunch of errors
    [CDE-3.kicad_sch, FAC-5.kicad_sch, FCM-7.kicad_sch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]
2026-07-03 fixing more errors
    [CDE-3.kicad_sch, FIN-8.kicad_sch, PCP-2.kicad_sch]
2026-07-05 fixing a whole bunch more ERC errors
    [CCE-2.kicad_sch, CDE-3.kicad_sch, CT1-4.kicad_sch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]
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2026-07-29 a lot more work on the circuit transcription
    [CDE-3.kicad_sch, CRC-1.kicad_sch, CT1-4.kicad_sch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]
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
